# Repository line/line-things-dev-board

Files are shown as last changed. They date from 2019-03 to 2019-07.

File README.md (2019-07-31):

# LINE Things development board
LINE Things development boardは、[Nordic Semiconductor nRF52832](https://www.nordicsemi.com/Products/Low-power-short-range-wireless/nRF52832)を搭載している[Raytac MDBT42Q](http://www.raytac.com/product/ins.php?index_id=31)モジュールを搭載したLINE Things実験用ボードです。
CPUボードとマザーボードの2つの基板から構成されています。組み合わせることで動作検証をすることや、CPUボードは単体でもブレッドボード等を使って実験を行うことが可能です。

[Adafruitがオープンソースで公開しているArduinoコア](https://github.com/adafruit/Adafruit_nRF52_Arduino)を利用可能なため、Arduino IDEで簡単にLINE Thingsの機能を実験することが可能です。

この資料では各ボードの使い方、ボード上に搭載しているデバイスに関しての詳細について紹介しています。
LINE ThingsやBluetooth LEの使い方などに関してはそれぞれのページを参照してください。

- [LINE Things - LINE Developers](https://developers.line.biz/ja/docs/line-things/)
- [LINE Things dev board使用ハンズオン](https://qiita.com/cpulabs/items/3a37a70cfa41129cb024)
- [LINE の IoT プラットフォーム LINE Things の Developer Trial を試してみる](https://engineering.linecorp.com/ja/blog/line-things-developer-trial/)
- [LINE Things 自動通信機能がリリースされました & 使い方紹介](https://engineering.linecorp.com/ja/blog/line-things-automatic-communication/)

### [重要] Groveコネクタを使う方への注意点

本体のみ使用する場合は問題ありませんが、 **Groveコネクタの基板の説明に間違い** があります。

* 基板上の**P2**と**P6**の説明が逆になっています。正しくは **P2** が I2C(5V) で、**P6** が I2C(3.3V) です。
* 基板上の**P7**と**P8**は説明が逆になっています。正しくは **P7** は Grove-I/O で、**P8** が Grove-UART です。

### [重要] 加速度センサを使う方への注意点

製造ロットにより、加速度センサを搭載していないもの、または動作しないものがります。
バージョン3以降のデフォルトファームウェアでは、加速度センサを検出できない場合、「-」を表示しています。

## 目次

[Documentation on Github Pages](https://line.github.io/line-things-dev-board/)

- README.md
  - [Quick Start](#quick-start)
  - [使用方法](#使用方法)
  - [使用上の注意](#使用上の注意)
  - [ハードウェア構成](#ハードウェア構成)
  - [拡張](#拡張)
  - [回路図・アートワーク図](#回路図アートワーク図)
- docs
  - [デフォルトファームウェアについて](docs/default-firmware.md)
  - [JavaScript から LINE Things Board を制御する](docs/js-control.md)
  - [ファームウェア書き込み方法](docs/update-firmware.md)
  - [Arduino で利用できるサンプルコード](docs/examples.md)
  - [うまく動かない場合](docs/trouble-shooting.md)

## Quick Start
予め書かれているファームウェアで、LINE Thingsの機能とボード上に搭載されたデバイスの体験をすることができます。
LINE Things上でモーターを除くすべてのデバイスの状態を取得することや、LEDの制御を行うことができます。
デバイスの電源を入れ、LINE App の LINE Things から接続することで、 Notify や デバイスへの Write を試すことができます。
初期状態のファームウェアは出力パワーを最低に設定しています。端末をデバイスに近づけて利用してください。

### 初めてLINE Thingsを使用する方
初めてLINE Thingsを使用する場合、まずはLINEアプリ内のQRコードリーダーでCPU基板の裏側、またはマザーボード基板にあるQRコードを読み取って利用規約に同意してください。



### デフォルトファームウェアの機能を使う
デフォルトファームウェアでは、ファームウェアを書き換えることなく、LIFFからLINEデバイスの挙動をより高度にコントロールする機能も用意しています。
この機能を用いると、例えば任意のタイミングでデバイスからNotifyさせたり、各種センサの値を任意に設定したり、取得することが可能です。
LIFFのJavaScript APIから、このデフォルトファームウェアの機能を簡単に使うためのライブラリも用意しています。

デフォルトファームウェアの仕様については、[デフォルトファームウェアについて](docs/default-firmware.md)を参照してください。
JavaScriptライブラリについては、[JavaScript から LINE Things Board を制御する](docs/js-control.md)を参照してください。
デフォルトファームウェアを利用したLIFFは [`liff-app/linethings-dev-default/`](liff-app/linethings-dev-default/) と [`liff-app/linethings-dev-js-control/`](liff-app/linethings-dev-js-control/) に格納されています。

このファームウェアは Advertising packet の Service UUID を LIFF 上から書き換える機能を持っています。
この機能は LINE Developers から Service UUID を取得して、LINE Things developers trial の独自デバイスを構築する際に、
ファームウェアと LIFF を変更することなく独自のデバイスとして使用することを目的とした機能です。

#### LIFFからService UUIDの変更と初期化
LINE Things Developer Trialでは、プロダクト登録とそれに対応したGATT Service UUIDの設定が必要です。
デフォルトファームウェアと LIFF ([`liff-app/linethings-dev-default/`](liff-app/linethings-dev-default/), [`liff-app/linethings-dev-js-control/`](liff-app/linethings-dev-js-control/)) では、LIFF上からService UUIDを書き換えることが可能です。
この機能を用いると、Service UUIDの書換の際にデバイスのファームウェアの書き換えが不要となります。

##### LIFFからService UUIDを書き換える
LINE AppからデフォルトのLIFFを開き、Write advertising packetタブを表示します。
設定したいService UUIDをテキストボックスに入れて書き換えボタンを押すと、
Dev boardのディスプレイに「BLE advertising uuid changed from LIFF....」 と表示されていれば成功です。

ディスプレイにこのメッセージが出ていることを確認して、 **LINE AppのLINE Thingsを閉じて、dev boardのリセットボタンを押して** ください。

##### Service UUIDを初期状態に戻す
電源が入っている状態で、マザーボード上のSW1タクトスイッチを押しながら、CPUボード上のリセットボタンを押してください。
起動時に `Set advertising packet UUID to default.` とディスプレイに表示されたら成功です。

### ファームウェアをカスタマイズする
[Adafruitがオープンソースで公開しているArduinoコア](https://github.com/adafruit/Adafruit_nRF52_Arduino)を利用して、Arduino IDEから簡単に開発することが可能です。

[LINE Things Starter](https://github.com/line/line-things-starter) も、LINE Things dev board に対応しています。
Starter のリポジトリから、LINE Things dev board 用のファームウェアを書き込んでください。

デフォルトファームウェアに戻したい場合には、[`arduino/linethings-dev-default/`](arduino/linethings-dev-default) を使用してください。

ハードウェアの仕様については、[ハードウェア構成](#ハードウェア構成)を参考にしてください。
ファームウェアの書き込み方法に関しては、[ファームウェア書き込み方法](docs/update-firmware.md)を参考にしてください。
[サンプルコード](docs/examples.md)にそれぞれのデバイスを制御する方法を載せています。

---

## 使用方法
### マザーボードにCPU基板を挿して使用する
ここではCPUボードをマザーボードに挿して使用する方法を説明します。
はじめに、CPUボードをマザーボードに差し込む場合は **方向を間違えないように必ず確認** してください。Bluetoothアンテナが基板の**外側**を向くようにとおぼえておくと良いでしょう。

#### 1. 電源を選択します
マザーボードは外部電源及びUSB駆動または電池駆動をさせることが可能です。これらの設定を行う前にかならず *SW3* の電源スイッチをOFFにしてください。
USB接続の場合はUSBケーブルを抜いてください。
電源の設定は *P4* ピンで行うことができます。上側に設定することで外部電源及びUSB駆動、下側を設定すると電池駆動になります。

motherboard_power

 * 外部電源及びUSB駆動
   * *P4* を写真のように正面から見て上側に設定してください。
 * 電池駆動
   * *P4* を写真のように正面から見て下側に設定してください。

※単4電池駆動の場合5V系は使用できません。外部電源駆動にして使用してください。 \
※USB電源駆動ではモーターを使用しないでください。外部電源駆動にして使用してください。

#### 2. 電源をONにします。

* 外部電源及びUSB駆動
  * *CN3* に電源を、またはUSBケーブルを接続してください。電源スイッチにかかわらずデバイスがONになります。
* 電池駆動
  * 電池を搭載して、*SW3* の電源スイッチをON(上側)にしてください。

電源LED(*DS1*)が光っていることを確認してください。以上で使用できる準備が整いました。

### CPU基板単体で使用する
電源さえ給電すれば単体動作可能となります。Resetピンは内部でプルアップしているので使用しない場合は非接続で構いません。

## 使用上の注意
### CPUボード
motherboard_direction

 * マザーボードに差し込む場合は必ず方向を間違えないように確認してください。
 * CPUボードを単体で使用する場合、安定したBLEの通信を行うため、アンテナが配置されている側をなるべくGNDや他の電極パターンに近づけないでください。ブレッドボード上に配置する場合は、アンテナをブレッドボードの端になるようにしてください。
 * BLE通信を行う場合、アンテナが露出していることが望ましいです。ケースに入れる場合は金属ケースなどを使用せず、プラスチックケースを使用してください。

### マザーボード
 * 基板上のP7とP8は説明が逆になっています。正しくはP7はGrove-I/Oで、P8がGrove-UARTです。
 * 基板上の説明ではP6にGrove-I2C 5Vと記載されていますが、正しくはP6がI2C(3.3V)、P2がI2C(5V)となります。
 * 電源供給として電池を使用する場合は、電池の極性を間違えないようにしてください。間違えた場合デバイスが破損してしまうことがあります。
 * 3.3Vを外部に供給する場合は、CPU基板を含め全体で600mAを超えない範囲で使用してください。超えてしまうと電源ICが破損してしまうことがあります。
 * 外部電源を使用する場合は必ず電圧と極性を確認してください。
 * 一部パターンのみ用意されていて、はんだ付けされていない部品があります。必要に応じて適宜追加してください。

---

## ハードウェア構成
### CPUボード
cpuboard

[Raytac MDBT42Q](http://www.raytac.com/product/ins.php?index_id=31)モジュールを搭載しています。
AdafruitのArduinoコアを利用可能でArduino IDEを使用して開発することができ、J-LINKなどから利用できるJTAG(SWD)ポートを用意しているので、
Arduinoではなくご自身でフルスクラッチ開発も可能となっています。マザーボードに挿して使用することも、CPUボード単体で使用することも可能です。

#### ピンアサイン
cpuboard_pinassign

#### 技術仕様
CPUボード単体での仕様です。マザーボードに接続して使用する場合、そちらの仕様が適用されます。

| 項目 | 値 |
----|----
| 動作可能電圧 | 1.7~3.6V |
| 最大RFパワー | 4dBm |
| Flashサイズ | 512KB |
| RAMサイズ | 64KB |

### マザーボード
motherboard

マザーボード上にはLED、タクトスイッチ、温度センサやOLEDなどを搭載しています。
使用する際はCPUボードを挿して使用します。**CPUボードを挿す際は向きに注意** してください。向きを間違うと
デバイスが壊れてしまうこともあるのでご注意ください。

#### 技術仕様
| 項目 | 値 |
----|----
| 電源ソース | 電池/USB/外部供給 |
| 動作可能電圧(電池) | 3V(単4電池1.5Vを２本直列) |
| 動作可能電圧(USB) | 5V |
| 動作可能電圧(外部供給) | 5V |
| 最大連続消費電流(電池駆動/モーター未使用) | 0.6A |
| 最大連続消費電流(モーター使用時) | 2.6A |

## マザーボード搭載デバイス
5V系統と記載があるものは電池駆動では使用できません。外部電源を使用するかUSB接続で使用する必要があります。また、GroveコネクタやGPIOにて3.3V駆動デバイスに5V系統を接続したり、
逆に5V駆動デバイスに3.3V系統を接続すると、マイコンや接続デバイスの破損につながるため、接続する電源系統はご注意ください。

特に記載がないものは3.3V系統です。5V系統のものに関しては明示的に記載しております。

### LED
LEDはアノード側がマイコンに接続されています。よってマイコンでHighを出力するとLEDが点灯します。使用する際はポートを出力設定にしてください。

| 基板上番号 | マイコンピン番号 |
----|----
| DS2 | 7 |
| DS3 | 11 |
| DS4 | 19 |
| DS5 | 17 |

### タクトスイッチ
タクトスイッチは回路上でプルアップしていないので、必ずマイコン側でプルアップ付き入力(INPUT_PULLUP)で使用してください。

| 基板上番号 | マイコンピン番号 |
----|----
| SW1 | 29|
| SW2 | 28 |

### ブザー
圧電ブザーが搭載されています。このブザーで音を鳴らすにはマイコンから交流信号を出力する必要があります(マイコンの出力をHighにしただけでは出力されません)。
通常のArduinoであればtone()関数で任意の音を出すことが可能ですが、nRF52832のArduino環境ではこれを使うことができません。よってタイマー割り込みなどでON/OFFを繰り返して音を鳴らす必要があります。
ここで紹介しているサンプルではFreeRTOSのタイマーを使って1KHzの割り込みを作り、そこでピンの状態を反転することで500Hzのブザー音を生成しています。
より高い周波数で鳴らしたい場合は、nRF52832のハードウェアタイマーを設定する必要があります。

| 基板上番号 | マイコンピン番号 |
----|----
| BZ1 | 27 |

### OLED
128x64ピクセルの有機EL(SSD1306)を搭載しています。I2Cで接続されており、
Adafruit SSD1306などのライブラリを使用すると簡単に使うことができます。I2Cのアドレスは0x3Dとなります。

| ピン名称 | マイコンピン番号 |
----|----
| SCL | 26 |
| SDA | 25 |

### 温度センサ
温度センサ(AT30TS74)を搭載しています。I2Cで接続されており、
簡単な制御で使うことができます。I2Cのアドレスは0x48となります。

| デバイスピン | マイコンピン番号 |
----|----
| SCL | 26 |
| SDA | 25 |

### 加速度センサ
加速度センサ(MMA8452Q)を搭載しています。I2Cで接続されており、
SparkFun MMA8452Q Accelerometerライブラリを使うと簡単な制御で使うことができます。I2Cのアドレスは0x1Cとなります。

| デバイスピン | マイコンピン番号 |
----|----
| SCL | 26 |
| SDA | 25 |

#### 注意事項
* 製造ロットにより、加速度センサを搭載していないもの、または動作しないものがります。
バージョン3以降のデフォルトファームウェアでは、加速度センサを検出できない場合、「-」を表示しています。

### モーター
モータードライバ(DRV8830)を2つ搭載することが可能です。I2Cで接続されており、
簡単な制御で使うことができます。モーターは *CN1* と *CN2* に接続することが可能です。I2Cのアドレスは0x60(CN1)、0x62(CN2)となります。

| デバイスピン | マイコンピン番号 |
----|----
| SCL | 26 |
| SDA | 25 |

#### 注意事項
* 初期状態でモータードライバは搭載されていません。使用するにはいくつかの部品を取り外し、必要な部品をご自身ではんだ付けする必要があります。
詳しくは[モータードライバ](#モータードライバ)を御覧ください。
* 5V系統です。電池駆動ではご使用になれません。使用する場合は外部電源またはUSB給電をする必要があります。

### Grove端子(I2C)
基板上では端子 *P6* となります。(基板上の説明ではP6にGrove-I2C 5Vと記載されていますが、正しくはP6がI2C-3.3V、P2がI2C-5Vとなります)

| コネクタピン番号 | ピン名称 | マイコンピン番号 |
----|----|----
| 1 | SCL | 26 |
| 2 | SDA | 25 |
| 3 | 3.3V  | - |
| 4 | GND | - |

#### 注意事項
* 初期状態でこのコネクタは搭載されていません。使用するにはGroveコネクタをご自身ではんだ付けする必要があります。
* 基板上の説明ではP6にGrove-I2C 5Vと記載されていますが、正しくはP6がI2C-3.3V、P2がI2C-5Vとなります。

### Grove端子(I2C / 5V系統)
基板上では端子 *P2* となります。

| コネクタピン番号 | ピン名称 | マイコンピン番号 |
----|----|----
| 1 | SCL | 26 |
| 2 | SDA | 25 |
| 3 | 5V  | - |
| 4 | GND | - |

#### 注意事項
* 初期状態でこのコネクタは搭載されていません。使用するにはGroveコネクタをご自身ではんだ付けする必要があります。
* 基板上の説明ではP6にGrove-I2C 5Vと記載されていますが、正しくはP6がI2C-3.3V、P2がI2C-5Vとなります。
* 5V系統です。電池駆動ではご使用になれません。使用する場合は外部電源またはUSB給電をする必要があります。
* 接続する機器は5Vで動作するものを接続してください。3.3Vのデバイスを接続するとデバイスが破損する可能性があるのでご注意ください。

### Grove端子(UART)
基板上に *P8 / Grove-I/O* と印刷されているコネクタです。（P7はGrove-I/Oで、P8がGrove-UARTです）

| コネクタピン番号 | ピン名称 | マイコンピン番号 |
----|----|----
| 1 | RxD | 6 |
| 2 | TxD | 8 |
| 3 | 3.3V  | - |
| 4 | GND | - |

#### 注意事項
* 初期状態でこのコネクタは搭載されていません。使用するにはGroveコネクタをご自身ではんだ付けする必要があります。

### Grove端子(汎用デジタルI/O)
基板上に *P7 / Grove-UART* と印刷されているコネクタです。（P7はGrove-I/Oで、P8がGrove-UARTです）

| コネクタピン番号 | ピン名称 | マイコンピン番号 |
----|----|----
| 1 | D0 | 2 |
| 2 | D1 | 3 |
| 3 | 3.3V  | - |
| 4 | GND | - |

#### 注意事項
* 初期状態でこのコネクタは搭載されていません。使用するにはGroveコネクタをご自身ではんだ付けする必要があります。

### GPIO
基板上では端子 *P1* となります。

6ピンはリセットピンです。Lowにすることでマイコンをリセットすることが可能です。CPU基板側でプルアップされているため、未使用の場合は非接続で構いません。

| コネクタピン番号 | ピン名称 | マイコンピン番号 |
----|----|----
| 1 | I/O | 2 |
| 2 | 5V | - |
| 3 | I/O | 3 |
| 4 | 3.3V | - |
| 5 | I/O | 4 |
| 6 | RESET | - |
| 7 | I/O | 5 |
| 8 | I/O | 26(SCL) |
| 9 | I/O | 12(SCK) |
| 10 | I/O | 25(SDA) |
| 11 | I/O | 13(MOSI) |
| 12 | I/O | 16 |
| 13 | I/O | 14(MISO) |
| 14 | I/O | 15 |
| 15 | I/O | 8(RxD) |
| 16 | O | 11(LED-DS3) |
| 17 | I/O | 6(TxD) |
| 18 | O | 7(LED-DS2) |
| 19 | GND |  |
| 20 | GND |  |

#### 注意事項
* 8, 10ピンはI2C端子に接続されています。このピンはボード上のI2Cデバイスでも使用しているため、汎用I/OではなくI2Cピンとして使用することを強くおすすめします。
* 15, 17ピンはUART端子に接続されています。このピンはファームウェアの書き込み等でも使用しているため、汎用I/OではなくUARTピンとして使用することを強くおすすめします。
* 16, 18ピンはボード上でLED端子に接続されています。そのため、基本的にOutput端子として使用してください。

## 拡張
### モータードライバ
マザーボードはモータードライバが実装されていないため、そのままではモーターを使用することができません。
モーターを使用したい場合は *R18* (0オーム)を取り外して、以下の部品を新規に追加実装してください。

DRV8830DGQRは裏のGNDパッドを基板の裏側からハンダを流してはんだ付けしてください。

| 追加部品基板シルク | 部品 | パラメータ |
----|----|----
| U1 | IC | DRV8830DGQR |
| U2 | IC | DRV8830DGQR |
| L1 | コイル | 100uF / 2A |
| C1 | コンデンサ | 1000pF |
| C2 | コンデンサ | 1000pF |
| C13 | コンデンサ | 100uF / 16V |
| C14 | コンデンサ | 470uF / 16V |
| R10 | 抵抗 | 0.2Ω / 2W |
| R11 | 抵抗 | 0.2Ω / 2W |
| CN1 | コネクタ | JST-XH-02P |
| CN2 | コネクタ | JST-XH-02P |

### 電源 / Groveコネクタ
電源コネクタはJST-XH-02Pコネクタを使用しています。Groveコネクタは4Pの標準のものを使用しています。

### 電池ボックス
電池ボックスは共立電子産業さん、または秋月電子通商さんにて購入可能な単4電池ボックスを2つ使用しています。

- http://eleshop.jp/shop/g/g6CM128/
- http://akizukidenshi.com/catalog/g/gP-02670/

## 回路図・アートワーク図
- CPU ボード
    - [回路図](https://github.com/line/line-things-dev-board/blob/master/schematics/cpu_board/Outputs/schematic.pdf)
    - [アートワーク図 - 表](https://github.com/line/line-things-dev-board/blob/master/schematics/cpu_board/Outputs/pcb_top.pdf)
    - [アートワーク図 - 裏](https://github.com/line/line-things-dev-board/blob/master/schematics/cpu_board/Outputs/pcb_bottom.pdf)
- マザーボード
    - [回路図](https://github.com/line/line-things-dev-board/blob/master/schematics/main_board/Outputs/schematic.pdf)
    - [アートワーク図 - 表](https://github.com/line/line-things-dev-board/blob/master/schematics/main_board/Outputs/pcb_top.pdf)
    - [アートワーク図 - 裏](https://github.com/line/line-things-dev-board/blob/master/schematics/main_board/Outputs/pcb_bottom.pdf)

### 自分で基板を製造したい
- [`/cpu_board/Outputs/`](/cpu_board/Outputs/)
- [`/main_board/Outputs/`](/main_board/Outputs/)

基板製造に必要なガーバーデータがここに格納されています。実装に必要な部品リストは bom_{cpu/main}_board.xls を使用してください。
なお、回路図及び基板データは Altium 社の Circuit Studio でデザインしています。設計データを変更する場合、Circuit Studio から開いてください。
https://www.altium.com/circuitstudio/

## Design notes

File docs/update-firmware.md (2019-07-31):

# ファームウェア書き込み方法
ここではArduino IDEを使用する方法を説明します。

## Arduino環境とドライバの準備
Arduino IDE をインストールた後、必ずボードを **接続しないで** 以下の手順を進めてください。

1. Arduino IDE を開きます
2. **Preferences** を開いてください
3. 'Additional Board Manager URL' に `https://www.adafruit.com/package_adafruit_index.json` を追加します
4. Tools -> Board menu　から **Boards Manager** を開いてください
5. "nRF52" と検索して、**Adafruit nRF52 by Adafruit** をインストールしてください (Version 0.11.0 以上をインストールしてください)
(*Note: Linux をお使いの方は追加でソフトウェアの設定が必要です、[こちらをご覧ください](https://learn.adafruit.com/bluefruit-nrf52-feather-learning-guide/arduino-bsp-setup)*)
6. [CP2102N driver](https://www.silabs.com/products/development-tools/software/usb-to-uart-bridge-vcp-drivers) をインストールします

## デフォルトファームウェア用のライブラリをインストール
デフォルトファームウェア ([`arduino/linethings-dev-default/`](/arduino/linethings-dev-default)) を利用する場合には、以下のライブラリが必要です。
Arduino のライブラリマネージャーからインストールしてください。

- [SparkFun MMA8452Q Accelerometer](https://github.com/sparkfun/SparkFun_MMA8452Q_Arduino_Library)
- [Adafruit GFX Library](https://github.com/adafruit/Adafruit-GFX-Library)
- [Adafruit SSD1306](https://github.com/adafruit/Adafruit_SSD1306)

また、温度センサーを動作させるために、`things_temp_lib` ライブラリを利用しています。
`things_temp_lib` は `library/things_temp_lib` をzipファイルに圧縮して、ライブラリをインクルードからインストールしてください。

## ハードウェアセットアップ
### マザーボードにCPU基板を刺して使用する
1. CPUボードがマザーボードに刺さっていることを確認してください
2. USB端子(J1)にMicro-USBケーブルを使ってPCへ接続してください
3. Tools -> Board のリストから **Adafruit Bluefruit Feather nRF52832** を選択してください
4. Under Tools -> Port で正しいシリアルポートを選択してください *ie. COM1, /dev/cu.SLAB_USBtoUART*
5. テストとして、一度空のスケッチをアップロードしてみましょう。エラーがでなければ問題ありません。

### CPU基板単体で使用する - マザーボードの書き込み機を利用
1. 下記図のようにCPUボードの *RxD*/*TxD*/*Reset*/*VCC*/*GND* ピンをジャンパ線などを使用してマザーボードに接続してください。ピンアサインはCPUボードのピンアサインを参照してください。
2. USB端子(*J1*)にMicro-USBケーブルを使ってPCへ接続してください
3. Tools -> Board のリストから **Adafruit Bluefruit Feather nRF52832** を選択してください
4. Under Tools -> Port で正しいシリアルポートを選択してください *ie. COM1, /dev/cu.SLAB_USBtoUART*
5. テストとして、一度空のスケッチをアップロードしてみましょう。エラーがでなければ問題ありません。

motherboard_external

### CPU基板単体で使用する - 市販されている書き込み機を使用(非推奨)
DTR信号を出力できるアダプタであれば市販されているUSB-TTL変換アダプタ (CP2102搭載基板等) を使って書き込むことができます。この他に0.1uFのセラミックコンデンサが必要です。

1. 下記図のようにCPU基板の *RxD*/*TxD*/*Reset*/*VCC*/*GND* ピンをジャンパ線などを使用して書き込み機に接続してください(**ResetピンとDTRピンの間には0.1uFのセラミックコンデンサを挟んでください**)
2. USB端子(*J1*)にMicro-USBケーブルを使ってPCへ接続してください
3. Tools -> Board のリストから **Adafruit Bluefruit nRF52 Feather** を選択してください
4. Under Tools -> Port で正しいシリアルポートを選択してください *ie. COM1, /dev/cu.SLAB_USBtoUART*
5. テストとして、一度空のスケッチをアップロードしてみましょう。エラーがでなければ問題ありません。

| 書き込み器側 | CPU基板側 | 注意点 |
----|----|----
| VDD(3.3V) | P28 | |
| GND | P1 | |
| DTR | P27 | 間に0.1uFのコンデンサを挟んでください |
| RxD | P6 | |
| TxD | P8 | |

cpuboard_prog_external

## 詳しい人向け
### J-LINKでの書き込み
J-LINKを使うとより高レベルのデバッグや、Arduinoを使用しない開発が可能となります。写真で示すJ-LINKコネクタの通りにデバッガを接続してください。
なお、J-LINKを使用して書き込みを行うと、もとのブートローダが破壊され、Arduino環境でのIDEが使用できなくなります。
さらに、工事設計認証(技適)を無効化してしまう可能性があります。よくわかる方のみ、ご自身の責任で行ってください。再度Arduino環境で使用できるように戻したい場合、
[Bootloaderを書き込む](#bootloaderを書き込む) を参考にして行ってください。

#### 配線図
cpuboard_jlink

| コネクタピン番号 | ピン名称 |
----|----|
| 1 | SWDIO |
| 2 | GND |
| 3 | SWDCLK |
| 4 | VCC |

### AdafruitのBootloaderを書き込む
一度、J-LINKを利用して書き込みを行い既存のブートローダーを破壊してしまった場合、初期状態のArduino開発環境を利用できるようにするには、Adafruitのブートローダーを再度書き込む必要があります。
作業にあたってはJ-LINKが必要となります。

[Arduino Core for Adafruit Bluefruit nRF52 Boards - Burning new Bootloader](https://github.com/adafruit/Adafruit_nRF52_Arduino/#burning-new-bootloader)を参考にして書き込みを行ってください。

※ 正常にArduino IDEから使用できている場合はこの作業を行わないでください。Bootloaderのバージョンを上げる場合は[Bootloaderの更新方法](#bootloaderの更新方法)を参考にしてください。

### Bootloaderの更新方法
Adafruit のページにアップデート方法が記載されています。この通りに行ってください。

https://learn.adafruit.com/bluefruit-nrf52-feather-learning-guide/updating-the-bootloader

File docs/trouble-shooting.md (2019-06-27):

# うまく動かない場合
## Bluetooth LEのデバイスが見つからない・通信がうまくできない
使用している端末のキャッシュが悪さをしている可能性があります。端末の設定からBluetoothをON/OFFしたり、一番確実なのは端末を再起動してみることです。

## Arduino IDEから書き込みや通信ができない・エラーが出る
Arduino IDEの `ツール -> ボード` で `Adafruit Bluefruit nRF52832 Feather` が選択されているか確認してください。
この項目がない場合はファームウェア書き込み方法 : Arduino環境とドライバの準備を参考にして環境構築を行ってください。

また、`ツール -> シリアルポート` で正しいポートが選択されているか確認してください。

これでもうまくいかない場合、ブートローダーや SoftDevice のバージョンの整合性が取れていなかったり、何らかの原因でブートローダが壊れてしまった可能性があります。
再度、ブートローダーを Arduino IDE から書き込むことで、書き込めるようになる可能性があります。
ブートローダーの書き込み方法は、[Arduino Core for Adafruit Bluefruit nRF52 Boards - Bootloader Support](https://github.com/adafruit/Adafruit_nRF52_Arduino/#bootloader-support) を参考にして行ってください。

## 電源LED(*DS1*)が光らない
電源設定ジャンパー(*J4*)が正しく設定されているか確認してください。USB電源または外部電源を使用している場合は上に、電池駆動の場合は下向きにジャンパーが入っていることを確認してください。電池駆動の場合、電池が正しい向きで挿入されているか確認してください。

## モーターが動かない
初期状態ではモーター駆動に必要な部品が搭載されていません。それらの部品をご自身で取り付ける必要があります。詳しくは [モータードライバ](#モータードライバ) を御覧ください。
部品を取り付けたのにもかかわらず動かない場合は、まずははんだ付けが正しく行われているか確認してください。

また、電池駆動ではモーターを動かすことはできません。USBまたは外部電源でのみ使用できます。

## 正しく動いていたものがデバッグ中に突然動かなくなった
I2Cデバイス(マザーボード上であればOLEDディスプレイ、温度センサ、加速度センサ)を使用している場合、それらの通信が何らかの原因でできなくなり、デッドロックになっている可能性があります。リセットではなく、一度電源を切ってから再度入れてみてください。

## モーターの制御が安定しない
DRV8830DGQRの裏側のGNDパッドがはんだ付けされていない可能性があります。なくても動きますが不安定になることがあります。基板の裏側からハンダを流し入れてください。

## Arduinoでサンプルファイルのコンパイルが通らない
Arduino の `Tools -> Board menu` から **Boards Manager** を開いて、"nRF52" と検索して、**Adafruit nRF52 by Adafruit** を見つけます。
インストールされているバージョンが **0.11.0** より古い場合は、アップデートしてください。

## デフォルトファームウェアのUUIDを変更して書き込んだが古いUUIDのまま変わらない
デフォルトサンプルファームウェアではUUIDを内蔵Flashに記憶しています。ファームウェア上で変更したUUIDを反映させるには、ファームウェアを書き込んだあとにUUIDの初期化を行い、
Flash上に記載されたUUIDを上書きをする必要があります。

[Service UUIDを初期状態に戻す](#service-uuidを初期状態に戻す)を参照して行ってください。

次に、スマートフォン側で、OS の Bluetooth デバイス連携画面からデバイス登録を解除し、その後 LINE App上の LINE Things のデバイス連携画面からも解除を行います。
通常、これで新たUUIDのデバイスと接続できるようになりますが、それでもだめな場合は LINE App を Kill して、OS の Bluetooth デバイス管理画面から Bluetooth を OFF/ON してみます。
これでも見つからない場合は、OS を再起動してください。

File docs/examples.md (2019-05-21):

# Arduino で利用できるサンプルコード

Arduino で、LINE Things development board 搭載デバイスを動作させるためのサンプルコードです。
ファームウェアの書き込み方法は、[ファームウェア書き込み方法](update-firmware.md) を参考にしてください。

## サンプルコード - LED
```cpp
/**
 * サンプルコード - LED
 * 0.5秒ごとにDS2~5が点灯してすべて点灯したら0.5秒に消灯を繰り返す
 */

const int LED_DS2 = 7;
const int LED_DS3 = 11;
const int LED_DS4 = 19;
const int LED_DS5 = 17;

void setup() {
  // LEDのピンを出力に設定
  pinMode(LED_DS2, OUTPUT);
  pinMode(LED_DS3, OUTPUT);
  pinMode(LED_DS4, OUTPUT);
  pinMode(LED_DS5, OUTPUT);
}

void loop() {
  // 500mSごとにLED_DS2~5を点灯
  digitalWrite(LED_DS2, HIGH);  // LED_DS2を点灯
  delay(500);                   // 500mS待つ
  digitalWrite(LED_DS3, HIGH);
  delay(500);
  digitalWrite(LED_DS4, HIGH);
  delay(500);
  digitalWrite(LED_DS5, HIGH);
  delay(500);
  // LED_DS2~5を消灯
  digitalWrite(LED_DS2, LOW);  // LED_DS2を消灯
  digitalWrite(LED_DS3, LOW);
  digitalWrite(LED_DS4, LOW);
  digitalWrite(LED_DS5, LOW);
  delay(500);
}
```

## サンプルコード - タクトスイッチ
```cpp
/**
 * サンプルコード - タクトスイッチ
 * SW1が押されているときだけLED_DS2が点灯
 */

const int LED_DS2 = 7;
const int SW1 = 29;

void setup() {
  // スイッチをプルアップ付き入力に設定
  pinMode(SW1, INPUT_PULLUP);
  // LEDのピンを出力に設定
  pinMode(LED_DS2, OUTPUT);
}

void loop() {
  // SW1が押されているときだけLED_DS2が点灯
  digitalWrite(LED_DS2, !digitalRead(SW1));
}
```

## サンプルコード - ブザー
```cpp
/**
 * サンプルコード - ブザー
 * 0.5秒ごとにブザーがON/OFFします
 */

const int BUZZER_PIN = 27;
SoftwareTimer buzzer;

// ブザーを鳴らすために1KHzの周期でイベントを生成
void buzzerEvent(TimerHandle_t xTimerID) {
  digitalWrite(BUZZER_PIN, !digitalRead(BUZZER_PIN));
}

void buzzerStart() {
  pinMode(BUZZER_PIN, OUTPUT);
  buzzer.begin(1, buzzerEvent);
	buzzer.start();
}

void buzzerStop() {
  buzzer.stop();
  digitalWrite(BUZZER_PIN, 0);
}

void setup() {
}

void loop() {
  buzzerStart();
  delay(500);
  buzzerStop();
  delay(500);
}
```

## サンプルコード - OLED
```cpp
/**
 * サンプルコード - OLED
 * `Adafruit SSD1306` と `Adafruit GFX Library` ライブラリをインストールしてください
 */

#include <Adafruit_SSD1306.h>
#include <Adafruit_GFX.h>
#include <Wire.h>

// ディスプレイのインスタンスを生成
Adafruit_SSD1306 display(128, 64, &Wire, -1);

void setup() {
  // ディスプレイの初期化
  display.begin(SSD1306_SWITCHCAPVCC, 0x3C);    // ディスプレイの表示に必要な電圧を生成, アドレスは0x3C
  display.clearDisplay();                       // ディスプレイのバッファを初期化
  display.display();                            // ディスプレイのバッファを表示
}

void loop() {
  // テキストを描画
  display.setTextSize(1);                       // テキストサイズ1
  display.setTextColor(WHITE);                  // Color White
  display.setCursor(0,10);                      // X=0, Y=10
  display.println("LINE Things");
  display.println("Starter Board");
  display.display();                            // ディスプレイのバッファを表示
  delay(1000);
  // 線を描画
  display.drawLine(0, 32, 128, 32, WHITE);      
  display.display();
  delay(1000);
  // 四角を描画
  display.fillRect(20, 40, 20, 20, WHITE);
  display.display();
  delay(1000);
  // 丸を描画
  display.fillCircle(100, 50, 10, WHITE);
  display.display();
  delay(1000);
  // 表示をクリア
  display.clearDisplay();                       // ディスプレイのバッファを初期化
  display.display();                            // ディスプレイのバッファを表示
  delay(100);
}
```

## サンプルコード - 温度センサ
```cpp
/**
 * サンプルコード - 温度センサ
 * 温度を読み込んでOLEDに表示するサンプルです。温度の表示にOLEDを使っています。
 * `library/things_temp_lib.zip` をライブラリをインクルードからインストールしてください
 * `Adafruit SSD1306` と `Adafruit GFX Library` ライブラリを管理からインストールしてください
 */

#include <Wire.h>
#include <Adafruit_SSD1306.h>
#include <Adafruit_GFX.h>
#include <linethings_temp.h>

//ディスプレイのインスタンスを生成
Adafruit_SSD1306 display(128, 64, &Wire, -1);

ThingsTemp temp = ThingsTemp();

void setup() {
  // ディスプレイの初期化
  display.begin(SSD1306_SWITCHCAPVCC, 0x3C);    // ディスプレイの表示に必要な電圧を生成, アドレスは0x3C
  display.clearDisplay();                       // ディスプレイのバッファを初期化
  display.display();                            // ディスプレイのバッファを表示

  // 温度センサの初期化
  temp.init();
}

void loop() {
  // 温度を取得
  float data = temp.read();
  // 温度を表示
  display.clearDisplay();                       // ディスプレイのバッファを初期化
  display.setTextSize(1);                       // テキストサイズ1
  display.setTextColor(WHITE);                  // Color White
  display.setCursor(0,10);                      // X=0, Y=10
  display.println("LINE Things");
  display.println("Starter Board");
  display.print("Temperature:");
  display.print(data);
  display.println("C");
  display.display();                            // ディスプレイのバッファを表示
  delay(1000);
}
```

## サンプルコード - 加速度センサ
```cpp
/**
 * サンプルコード - 加速度センサ
 * 加速度センサの値を読み込んでOLEDに表示するサンプルです。表示にOLEDを使っています。
 * `SparkFun MMA8452Q Accelerometer` ライブラリを管理からインストールしてください
 * `Adafruit SSD1306` と `Adafruit GFX Library` ライブラリを管理からインストールしてください
 */

#include <Wire.h>
#include <Adafruit_SSD1306.h>
#include <Adafruit_GFX.h>
#include <SparkFun_MMA8452Q.h>

// ディスプレイのインスタンスを生成
Adafruit_SSD1306 display(128, 64, &Wire, -1);
// 加速度センサのインスタンスを生成 (アドレス: 0x1c)
MMA8452Q accel(0x1c);

void setup() {
  // ディスプレイの初期化
  display.begin(SSD1306_SWITCHCAPVCC, 0x3C);    // ディスプレイの表示に必要な電圧を生成, アドレスは0x3C
  display.clearDisplay();                       // ディスプレイのバッファを初期化
  display.display();                            // ディスプレイのバッファを表示

  // 加速度センサの初期化
  accel.init(SCALE_2G);
}

void loop() {
  // 加速度センサから値を取得
  if (accel.available()) {
    accel.read();
  }

  // 加速度センサの値を表示
  display.clearDisplay();                       // ディスプレイのバッファを初期化
  display.setTextSize(1);                       // テキストサイズ1
  display.setTextColor(WHITE);                  // Color White
  display.setCursor(0,10);                      // X=0, Y=10
  display.println("LINE Things");
  display.println("Starter Board");
  display.print("X:");
  display.println(accel.cx);
  display.print("Y:");
  display.println(accel.cy);
  display.print("Z:");
  display.println(accel.cz);
  display.display();                            // ディスプレイのバッファを表示
  delay(300);
}
```

## サンプルコード - モーター
```cpp
/**
 * サンプルコード - モーター
 * 2つのモーターを制御するサンプルです
 * library/things_motor_lib.zipをライブラリをインクルードからインストールしてください
 */

#include <linethings_motor.h>

ThingsMotor motor_cn1 = ThingsMotor(MOTOR_ADDR_CN1);
ThingsMotor motor_cn2 = ThingsMotor(MOTOR_ADDR_CN2);

int i = 0;

void setup() {
  motor_cn1.init();
  motor_cn2.init();
}

void loop() {
  motor_cn1.control(MOTOR_BACK, i);
  motor_cn2.control(MOTOR_FORWARD, i);
  delay(100);
  i++;
  if (i >= 100) {
    i = 0;
  }
}
```

## マザーボード上以外のデバイスを使ったサンプルスケッチ

### フルカラー LED - NeoPixel
neopixel

一般的にNeopixelとよばれる、WS2812B搭載のフルカラーLEDを光らせるデモです。LEDの光の輝度を時間とともに0~100%でコントロールしています。マザーボード上の *SW1* を押すことでLEDの色を変えることができます。
GPIOの1ピン(マイコン *IO2*)にNeopixelのIN端子を、GPIOの3番ピン(3.3V)を *VCC*、20番ピン(GND)を *GND* に接続します。本来WS2812Bは5Vで使用するものですが、3.3V電源でも一応動くことを確認しています。

ファームウェアは `arduino/linethings-dev-neopixel/linethings-dev-neopixel.ino` を使用してください。
使用する基板に搭載されたLED数に従って `NEOPIXEL_PIXELS` の値を変更してください。初期値は16個のLEDを制御します。

Adafruit_NeoPixelライブラリを使用しています。ライブラリを管理から `adafruit neopixel` と検索して見つかる `Adafruit Neopixel by Adafruit` をインストールしてください。

### RC car
マザーボード上に搭載されたモータードライバを使ったラジコンです。LINE Thingsを使ってコントロールすることが可能です。
ファームウェアは `arduino/linethings-dev-car/linethings-dev-car.ino` を使用してください。LIFFは `liff-app/linethings-dev-car/` においてあるものを使用します。

### 注意事項
* マザーボード基板上の電池のみでは動作しません。外部電源コネクタを使用して給電します。
* USB電源はパソコンなどから給電すると電圧が不安定になり動作しない場合があります。また流れる電流に注意が必要なのでおすすめしません。

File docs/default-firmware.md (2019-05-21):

# デフォルトファームウェアについて

## GATT サービスの仕様
デフォルトファームウェアに実装されているGATTサービス・キャラクタリスティックの仕様について説明します。
ここからの説明は[JavaScriptライブラリ](js-control.md)を使用する際には不要ですが、拡張したり、LIFF以外からデバイスを制御する場合に必要な情報です。

### Characteristic の説明
PSDIを除く全てのCharacteristicは、以下のサービスに実装されています。

- `DEVBOARD_SERVICE_UUID`
  - `f2b742dc-35e3-4e55-9def-0ce4a209c552`

このサービスに実装されている Characteristic と UUID は以下の通りです。

|説明 | 名称 | UUID | 属性 | サイズ(固定長) |
----|----|----|----|----
| 1 | WRITE_BOARD_STATE_CHARACTERISTIC_UUID | 4f2596d7-b3d6-4102-85a2-947b80ab4c6f | Write | 20Byte |
| 2 | VERSION_CHARACTERISTIC_UUID | be25a3fe-92cd-41af-aeee-0a9097570815 | Read | 1Byte |
| 3 | NOTIFY_SW_CHARACTERISTIC_UUID | a11bd5c0-e7da-4015-869b-d5c0087d3cc4 | Notify | 2Byte |
| 4 | NOTIFY_TEMP_CHARACTERISTIC_UUID | fe9b11a8-5f98-40d6-ae82-bea94816277f | Notify | 2Byte |
| 5 | COMMAND_WRITE_CHARACTERISTIC_UUID | 5136e866-d081-47d3-aabc-a2c9518bacd4 | Write | 18Byte |
| 6 | COMMAND_RESPONSE_CHARACTERISTIC_UUID | 1737f2f4-c3d3-453b-a1a6-9efe69cc944f  | Read + Notify | 4Byte |

1. JavaScriptライブラリ内では、Service UUIDの書き換えのみで使用しています。
2. Dev boardのファームウェアのバージョンを取得します。デバイス側で定義されていない場合はVersion 1とします。
3. Switchのnotifyが有効化されているとき、スイッチイベントが発生するときにnotifyします。
4. 温度センサのnotifyが有効化されているとき、一定間隔で温度をnotifyします。
5. Dev boardのデバイスの設定や、notifyの設定など、コマンドを書き込むために使用します。
6. Dev boardから、コマンドに対応したデータがある場合、それを取得するために利用します。Notify にも対応しています。

### WRITE_BOARD_STATE_CHARACTERISTIC_UUID (Service UUIDの書き換え)
Service UUIDの書き換えを行うためのキャラクタリスティックです。
`Write device`はボード上のデバイスの値を書き換えることができますが、これは `/liff-app/linethings-dev-default` が使用しているものです。

フォーマット

| |Command (1Byte) | reserved (2Byte) | hash (1Byte) | payload (16Byte) | 説明 |
----|----|----|----|----|----
| Write device | 0 | {0, 0} | 0 | see code | ボード上のデバイスとGPIOを一括設定する際に使用します。Version 1から使用できます|
| Write Service UUID | 1 | {0, 0} | hash of uuid | uuid | hashはUUIDをリダクション加算した値を使用します。UUIDは"-"は省略します |

### VERSION_CHARACTERISTIC_UUID (ファームウェアのバージョン取得)
Firmwareのバージョンを取得します。Version 1ではこのキャラクタリスティックが実装されていませんでした。
そのため、LIFF側からこのキャラクタリスティックのReadがerrorとなった場合は
Version 1であるとして、Version 2以降で追加となったService UUIDの書き換え機能以外は非対応としなくてはいけません。

### NOTIFY_SW_CHARACTERISTIC_UUID (SW Notify)
スイッチが押されたタイミングでnotifyをします。
`DEFAULT_CHARACTERISTIC_IO_WRITE_UUID`にてSWのnotifyの設定が可能です。
初期状態では、source = SW1 & SW2, mode = `CHANGE`, interval = 50ms に設定されています。

フォーマット

|value[1]|value[0]|
----|----
|address(1:SW1, 2:SW2)|SW value|

### NOTIFY_TEMP_CHARACTERISTIC_UUID (Temperature Notify)
`DEFAULT_CHARACTERISTIC_IO_WRITE_UUID`にて温度のnotitfyが有効化された場合、設定されたタイミングでnotifyをします。
notifyされる16Byteの温度データは100倍されたものが送信されます。

初期状態では、source = 1, interval = 10000ms に設定されています。

### COMMAND_WRITE_CHARACTERISTIC_UUID (デバイス操作)
ボード上のデバイスの設定や、Notifyの設定などを行います。

フォーマット

| |Command (1Byte) | Payload (17Byte) | 説明 |
----|----|----|----
| Control display | 0 | {0, 0, 0, 0, 0, 0, 0, 0, 0, 0, 0, 0, 0, 0, 0, address_x, address_y} | Write textで使用するindexアドレスを指定します | |
| Write text | 1 | {length of text, (text max 16Byte)} | 任意のテキストを書き込み | Control displayで設定したアドレスは自動的にインクリメントされません|
| Clear display| 2| don't care | ディスプレイをクリア| |
| Write LED | 3 | {0, 0, 0, 0, 0, 0, 0, 0, 0, 0, 0, 0, 0, 0, 0, port, value} |  |
| Buzzer | 4 | {0, 0, 0, 0, 0, 0, 0, 0, 0, 0, 0, 0, 0, 0, 0, 0, value(0:OFF / 1:ON)} |  |
| GPIO Direction | 5 | {0, 0, 0, 0, 0, 0, 0, 0, 0, 0, 0, 0, 0, 0, 0, port, direction(0:Input / 1:Output)} |  |
| GPIO Digital Write  | 6 | {0, 0, 0, 0, 0, 0, 0, 0, 0, 0, 0, 0, 0, 0, 0, port, value} |  |
| GPIO Analog Write  | 7 | {0, 0, 0, 0, 0, 0, 0, 0, 0, 0, 0, 0, 0, 0, 0, port, value} |  |
| I2C Start transmission | 8 | {0, 0, 0, 0, 0, 0, 0, 0, 0, 0, 0, 0, 0, 0, 0, 0, address} |  |
| I2C Write data | 9 | {0, 0, 0, 0, 0, 0, 0, 0, 0, 0, 0, 0, 0, 0, 0, 0, data} |  |
| I2C Stop transmission | 10 | {0, 0, 0, 0, 0, 0, 0, 0, 0, 0, 0, 0, 0, 0, 0, 0, 0} |  |
| I2C Request from | 11 | {0, 0, 0, 0, 0, 0, 0, 0, 0, 0, 0, 0, 0, 0, 0, 0, address} |  |
| I2C Read request | 12 | {0, 0, 0, 0, 0, 0, 0, 0, 0, 0, 0, 0, 0, 0, 0, 0, 0} |  |
| Set digital GPIO port for read | 13 | {0, 0, 0, 0, 0, 0, 0, 0, 0, 0, 0, 0, 0, 0, 0, 0, port} |  |
| Set analog GPIO port for read | 14 | {0, 0, 0, 0, 0, 0, 0, 0, 0, 0, 0, 0, 0, 0, 0, 0, port} |  |
| Set display font size| 15 | {0, 0, 0, 0, 0, 0, 0, 0, 0, 0, 0, 0, 0, 0, 0, 0, fontsize(1~3)} |  |
| Write LED Byte | 16 | {0, 0, 0, 0, 0, 0, 0, 0, 0, 0, 0, 0, 0, 0, 0, 0, value} |  |
| SW Notify config | 17 | {0, 0, 0, 0, 0, 0, 0, 0, 0, 0, 0, 0, 0, source(0:Disable / 1:SW1, 2:SW2, 3:SW1 & SW2), mode(0:LOW / 1:CHANGE / 2:RISING / 3:FALLING), interval[1], interval[0]} |  |
| Temperature Notify config | 18 | {0, 0, 0, 0, 0, 0, 0, 0, 0, 0, 0, 0, 0, 0, source(0:Disable / 1:Temperature), interval[1], interval[0]} |  |
| Read value request | 32 | {0, 0, 0, 0, 0, 0, 0, 0, 0, 0, 0, 0, 0, 0, 0, source(0:SW / 1:Accel / 2:Temp / 3:DIgital GPIO / 4:Analog GPIO / 5:I2C)} |  |

### COMMAND_RESPONSE_CHARACTERISTIC_UUID (デバイスからread)
`COMMAND_WRITE_CHARACTERISTIC_UUID`にて設定されたデバイスの値を取得します。設定されたデバイスソースによって、送信されるデータが異なります。

|Source|Value format|
----|----
|Switch|{0, 0, SW2, SW1}|
|Accel| {0, X, Y, Z} |
|Temperature|温度が100倍された値 |
|GPIO Digital| {0, 0, 0, value} |
|GPIO Analog| {0, 0, 0, value}|
|I2C| {0, 0, (0:invalid / 1:valid), value} |

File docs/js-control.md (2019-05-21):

# JavaScript から LINE Things Board を制御する

LINE Things developemt boardのファームウェアが持っているGATT Characteristicを利用することで、
自由にボードに乗っているハードウェアや GPIO を簡単に制御することができるようになっています。

ここで紹介する方法を用いると、ファームウェアの書き換えなしに、LIFFのJavaScriptによってデバイスの挙動を設定することが可能です。
制御を簡単に行うための、JavaScriptクラスを用意しています。
例えば任意のタイミングでデバイスからNotifyさせたり、各種センサの値を任意に設定したり、取得することが可能です。
LIFFからだけではなく、自動通信など、キャラクタリスティックに読み書きができる環境であれば、同じようにデバイスの操作をすることが可能です。

なお、このキャラクタリスティックからディスプレイ操作をすると、デバイスのOLEDの表示は更新されなくなります。
再度自動的に表示させたい場合はデバイスの電源を入れ直すかリセットボタンを押してください。

`liff-app/linethings-dev-js-control` に格納されているコードではここで紹介している方法でコントロールできる全ての機能を試すことができます。
まずはこちらを試してみると雰囲気をつかめるかもしれません。

その他サンプルコードを、`liff-app/examples-js-control` に格納しているので、こちらを参考にしてみてください。

## 利用するにあたって
この機能を利用する場合はLINE Things development boardのFirmwareバージョンが2以上でなくてはなりません。
LIFFを開いた際、アラートが表示された場合はファームウェアのアップデートをしてください。

詳しくは[ファームウェアの書き込み方法](https://github.com/line/line-things-dev-board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)
を御覧ください。

## LIFF からの利用方法
JavaScriptから利用するためのクラスは`things-dev-board.js` に実装されています。
使用する際にはhtmlからこのファイルを読み込んでください。
LIFF の BLE プラグインに対して、`requestDevice()` した際に帰ってくる返り値をコンストラクタに代入して `connect()` してください。

利用するには、LINE EngineeringにてLIFFのendpointを作成したLIFFに設定する必要があります。
いくつかサンプルを用意しています。初めて利用する際はそれを参考にしたり、拡張すると便利です。
(GitHub pages も利用可能です)

|ファイル名|内容|
----|----
|default|利用できるすべての機能を試してみることができます|
|display|LIFFからデバイスのOLEDを制御するサンプルです|
|led-blink|LIFFからLEDを制御します。Arduinoライクにsetup(), loop()を利用できるようにしています|
|notify|SWとTemperatureの値を定期的にnotifyするサンプルです|

led-blinkはloopコードを含んでいます。あくまでArduinoライクに動かすためにそうしていますが、端末の電力を消費します。
本来はイベントドリブンで書くべきなので、あくまでも動かせるデモとしてのみ参考にしてみてください。

## JavaScriptライブラリ機能詳細

### Service UUIDの書き換え
`writeAdvertUuid(uuid)`
uuidにはテキストとして書き換えたいUUIDを設定します。なお、このメソッドを実行しても即座には反映さ
れず、デバイスのリセットとLIFFの再立ち上げが必要です。

この機能のみ、Version 1から利用可能です。

一度書き換えたUUIDはデバイスのFlashに格納されて、電源を切ったとしても最後に書き込んだService UUIDが使用されます。
デフォルトのService UUIDに戻したい場合、SW1スイッチを押しながらリセットボタンを押してください。

### Versionの読み込み
`deviceVersionRead()`
このメソッドを実行したあと、 `versionRead()` にてファームウェアのバージョンを取得します。
なお、以前のバージョンのファームウェアはバージョン情報のキャラクタリスティックが存在しないため、
存在しないキャラクタリスティックとして検出し、その場合はバージョン1を返します。

これから説明している機能はVersion 2以上で利用可能となります。

### Display 制御
この操作を行うと、ボード上でディスプレイの更新は行われなくなり、完全にこれから紹介する方法で
ディスプレイの表示内容を操作することになります。
もとに戻したい場合は、デバイスの電源を入れ直すかリセットボタンを押します。

#### ディスプレイクリア
`displayClear()`
ディスプレイ表示をクリアします。

#### ディスプレイ書き込みポジション指定
`displayControl(addr_x, addr_y)`
テキストを書き込むアドレスを指定します。それぞれ0~63の値を取ります。

#### キャラクタフォントサイズ指定
`displayFontSize(size)`
フォントサイズを指定します。指定可能な値は1, 2, 3です。

#### キャラクタ書き込み
`displayWrite(text)`
textには書き込みたい文字列(最大16文字)を指定します。16文字を消える場合は複数回に分けて実行します。

### LED制御
#### 単体制御
`ledWrite(port, value)`
portは対象のLEDを指定します。2~5を指定可能です。それぞれデバイスのLED DS2~5が対応しています。valueは0で消灯、1で点灯です。

#### 全体制御
`ledWriteByte(value)`
全てのLEDを一度の制御します。

### ブザー制御
`buzzerControl(value)`
1を書き込むとbuzzerがなります。

### GPIOデジタル制御
#### 入出力設定
`gpioPinMode(port, value)`
portは対象のGIPOポートを指定します。valueは0でINPUT, 1でOUTPUTです。

#### 出力
`gpioDigitalWrite(port, value)`
portは対象のGIPOポートを指定します。valueは対象ポートの出力レベルを0または1で設定します。

### GPIOアナログ出力
`gpioAnalogWrite(port, value)`
portは対象のGIPOポートを指定します。valueは対象ポートの出力レベルを0から255で指定します。

### I2C
`i2cStartTransmission(address)`
`i2cWrite(value)`
`i2cStopTransmission()`
`i2cRequestFrom(address, length)`
`i2cReadRequest(device)`

基本的にはArduinoのI2Cと同じように使用するので、そちらを参考にしてください。 `i2cReadRequest(device)` は
I2Cデバイスからデータを読み込み、Dev Board内のバッファに格納します。実際のそのデータをLIFFに転送するには
 `readReq(cmd)` と `deviceRead()` を組み合わせて行います。

### デバイスからのデータリード
デバイスからのデータリードは2段階で行われます。まず、デバイス内で読み込みたいデータをそれぞれのバッファに格納します。
deviceおよびportで対象となるデバイスのアドレスや、読み込むポート番号を指定します。なお、スイッチ、加速度センサ、
温度に関してはこのステップは不要で、いきなり `readReq(cmd)` を実行します。

`i2cReadRequest(device)`
`gpioDigitalReadReq(port)`
`gpioAnalogReadReq(port)`

読み込みたいデータをバッファに格納したら、実際に読み込みたいソースを指定します。
`readReq(cmd)`

|値|説明|
----|----
|0|Switch|
|1|加速度センサ|
|2|温度|
|3|デジタルGPIOの値|
|4|アナログGPIOの値|
|5|I2Cのデータ|

最後に、`deviceRead()`を実行して、デバイスのバッファに格納されたデータを読み取ります。

### Notification
#### Switch
`swNotifyEnable(source, mode, interval, callback)`
スイッチの状態に変化が起きたときだけNotifyします。`swNotifyDisable()`で停止します。
##### source

|値|説明|
----|----
|0|disable|
|1|SW1|
|2|SW2|
|3|SW1 or SW2|

##### mode

|値|説明|
----|----
|0|LOW|
|1|CHANGE|
|2|RISING|
|3|FALLING|

##### interval
一度割り込みを起こしてから次に割り込みを許可するまでの時間をミリ秒で指定します。これを使用することでチャタリング防止機能をつけることが可能です。

##### callback
Notificationが発生したときに実行されるメソッドを指定します。

#### Temperature
`tempNotifyEnable(interval, callback)`
温度を定期的にNotifyします。`tempNotifyDisable()`で停止します。
なお、 `i2cStartTransmission(address)`を実行したあと、この機能は `i2cStopTransmission()` が実行されるまで無視されます。

##### source

|値|説明|
----|----
|0|disable|
|1|enable|

##### callback
Notificationが発生したときに実行されるメソッドを指定します。

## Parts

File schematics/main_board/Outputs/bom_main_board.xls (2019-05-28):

LibRef | Designator | Quantity | value | Footprint | Description | 部品メーカー | メーカー品番 | 代替可否 | 部品提供 | 実装なし | コメント
PKLCS1212E4001 | BZ1 | 1 |  | PKLCS1212E4001 | PKLCS1212E4001 | Murata | PKLCS1212E4001-R1
Cap1 | C1, C2 | 2 | 1000pF | 2012[0805] |  | Yageo | CC0805KRX7R9BB102 | ok
Cap1 | C3, C4, C5, C9, C12 | 5 | 0.1uF | 2012[0805] |  | Yageo | CC0805ZRY5V9BB104 | ok
Cap1 | C6, C15, C16 | 3 | 4.7uF | 2012[0805] |  | Murata | GRM21BR71A475ME51L | ok
Cap1 | C7, C8 | 2 | 300pF | 2012[0805] |  |  |  |  |  | yes
Cap1 | C10, C11, C17 | 3 | 10uF | 2012[0805] |  | Yageo | CC0805MKY5V6BB106 | ok
Cap2 | C13 | 1 | 100uF | CE04-8 |  |  |  |  |  | yes
Cap2 | C14 | 1 | 470uF | CE04-8 |  |  |  |  |  | yes
B2B-XH-A | CN1, CN2, CN3 | 3 |  | CND-B2B-XH-A | XHシリーズ ベース付ポスト トップ型 2.5mmピッチ 250V 3A |  |  |  |  | yes
LL4148 | D1 | 1 |  | SOD80 |  | ON Semiconductor | LL4148 | ok
SS14 | D2 | 1 |  | DO-214AC |  | Taiwan Semiconductor | SS12 E3
LED | DS1, DS2, DS3, DS4, DS5, DS6, DS7 | 7 |  | 3216[1206]+A |  | Light-On | LTST-C150GKT | ok
USB-B | J1 | 1 |  | USB-B-MICRO | USB 1.1, Right Angle, Thru-Hole, B Type, Receptacle, 4 Position, White | Amphenol FCI | 10104110-0001LF | ok
Inductor | L1 | 1 | 100uH | INDUCTOR-1212 |  |  |  |  |  | yes
NRF52-MODLE | M1 | 1 |  | NRF52-MODLE | NRF52-MODLE |  |  |  | yes |  | 14P Pin Header * ２
SSD1306-096-12864 | M2 | 1 |  | SSD1306-096-12864 | SSD1306-096-12864 |  |  |  | yes |  | 4P Pin Frame * 1
BH-4-4P | M3, M4 | 2 |  | BH-4-4P | BH-4-4P |  |  |  |  | yes
Header 10X2 | P1 | 1 |  | HDR2X10 | Header, 10-Pin, Dual row |  |  |  |  | yes
1125-4P | P2, P6, P7, P8 | 4 |  | 1125-4P | Seed Studio Grobe connector |  |  |  |  | yes
Header 2 | P3 | 1 |  | HDR1X2 | Header, 2-Pin |  |  |  |  | yes
Header 3 | P4 | 1 |  | HDR1X3 | Header, 3-Pin |  |  |  | yes |  | 3P Pin Header * 1
Header 6 | P5 | 1 |  | HDR1X6 | Header, 6-Pin |  |  |  |  | yes
2N7002 | Q1, Q2 | 2 |  | SOT23-3 | N-Channel MOSFET | ON Semiconductor | 2N7002KT1G | ok
Res | R1, R2, R3, R4, R5, R14, R15, R17, R20 | 9 | 1k | 2012[0805] |  | Vishay | CRCW08051K00JNEAC | ok
Res | R6, R7, R8, R9 | 4 | 4.7k | 2012[0805] |  | Vishay | CRCW08054K70JNEAC | ok
Res | R10, R11 | 2 | 0.2 | 6332[2512] |  |  |  |  |  | yes
Res | R12 | 1 | 470 | 2012[0805] |  | Yageo | RC0805JR-07470RL | ok
Res | R18 | 1 | 0 | 2012[0805] |  | Bourns | CR0805-J/-000ELF | ok
Res | R19 | 1 | 100k | 2012[0805] |  | Bourns | CR0805-FX-1003ELF | ok
TL3342F160QG | SW1, SW2 | 2 |  | TL3342F160QG |  | E-Switch | TL3342F160QG | ok
MSK-12C01-07 | SW3 | 1 |  | MSK-12C01-07 |  | ALPS | SSSS811101 | ok
DRV8830DGQR | U1, U2 | 2 |  | MSOP10TPH | DRV8830DGQR |  |  |  |  | yes
MMA8452Q | U3 | 1 |  | QFN16-0.5 | MMA8452AQ | NXP | MMA8452QR1
AT30TS74 | U4 | 1 |  | SOIC8 | AT30TS74 | Microchip | AT30TS74-SS8M-T
CP2102N | U5 | 1 | Value | QFN28-0.5 | CP2102N | Silicon Labs | CP2102N-A01-GQFN28R
DMG3415 | U6 | 1 |  | SOT23-3 | DMG3415 | Diodes Incorporated | DMG3415U-7
AP2112 | U7 | 1 |  | SOT23-5 | AP2112 | Diodes Incorporated | AP2112K-3.3TRG1

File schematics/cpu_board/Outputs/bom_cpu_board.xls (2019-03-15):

LibRef | Designator | Quantity | value | Footprint | Description | 部品メーカー | メーカー品番 | 実装なし | コメント
Cap1 | C1 | 1 | 10uF | 1608[0603] |  | Taiyoyuden | JMK107ABJ106MA-T
Cap1 | C2 | 1 | 1uF | 1608[0603] |  | Taiyoyuden | LMK107B7105MA-T
Cap1 | C3, C4 | 2 | 12p | 1608[0603] |  | Kemet | C0603C120J5GACTU
LL4148 | D1 | 1 |  | SOD80 |  | ON Semiconductor | LL4148
Inductor | L1 | 1 | 10uH | 2012[0805] |  | Taiyoyuden | LBR2012T100K
MDBT42Q | M1 | 1 |  | MDBT42Q | MDBT42Q | Raytac | MDBT42Q-512KV2
Header 14 |  | 2 |  | HDR1X14 |  |  |  |  | 14P Pin Headerを２つつける（Designatorはないが、基板の両端)
Header 4 | P1 | 1 |  | HDR1X4 |  |  |  | yes
Res | R1 | 1 | 10k | 1608[0603] |  | Yageo | RC0603JR-0710KL
TL3342F160QG | SW1 | 1 |  | TL3342F160QG |  | E-Switch | TL3342F160QG
XTAL-MC-146 | Y1 | 1 | 32.768KHz | MC-146 |  | EPSON Timing | MC-146 32.7680KA-A0:ROHS

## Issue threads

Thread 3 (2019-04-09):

回路図、アートワーク図のPDFファイル

matsujirushi, 2019-04-09:
Circuit Studioをインストールしなくても確認できるように、回路図、アートワーク図をPDFファイルでアップロードしていただけないでしょうか。
よろしくお願い致します。

cpulabs, 2019-04-10:
表・裏のアートワーク図を追加しました。回路図のリンクは間違っていたので修正しました。

Closed 2019-04-10.

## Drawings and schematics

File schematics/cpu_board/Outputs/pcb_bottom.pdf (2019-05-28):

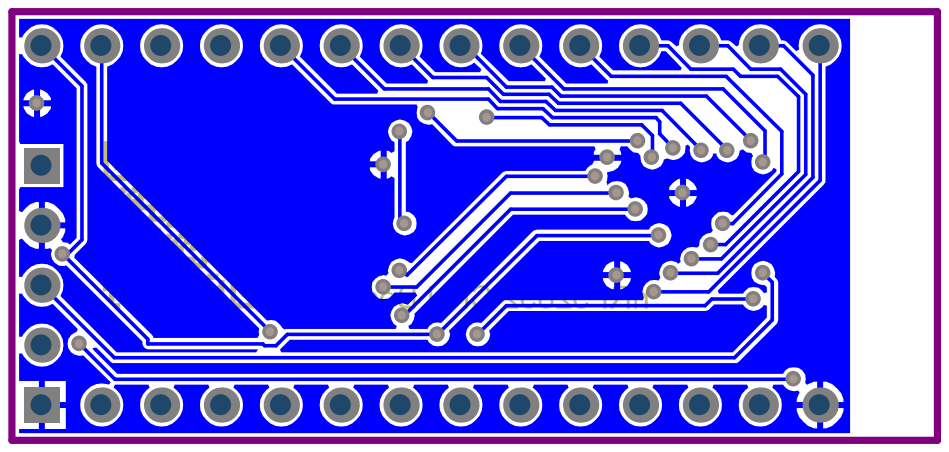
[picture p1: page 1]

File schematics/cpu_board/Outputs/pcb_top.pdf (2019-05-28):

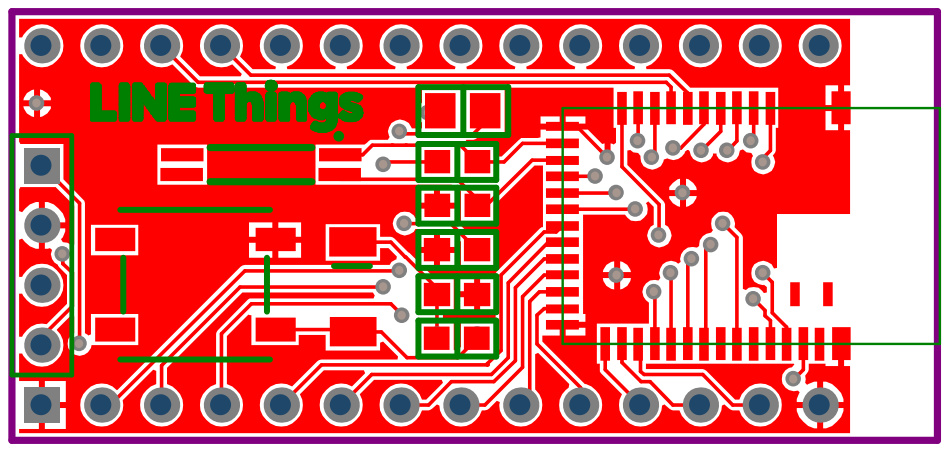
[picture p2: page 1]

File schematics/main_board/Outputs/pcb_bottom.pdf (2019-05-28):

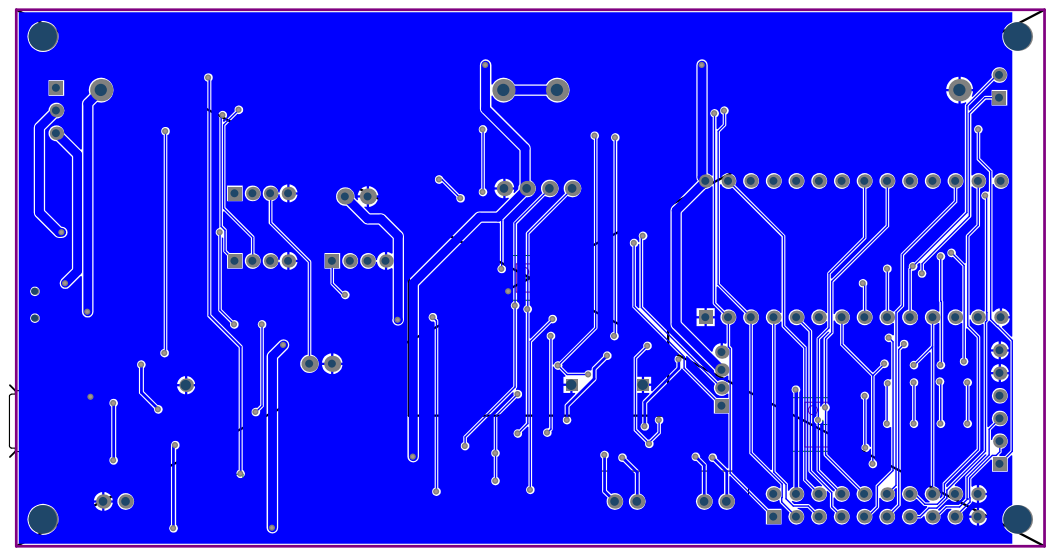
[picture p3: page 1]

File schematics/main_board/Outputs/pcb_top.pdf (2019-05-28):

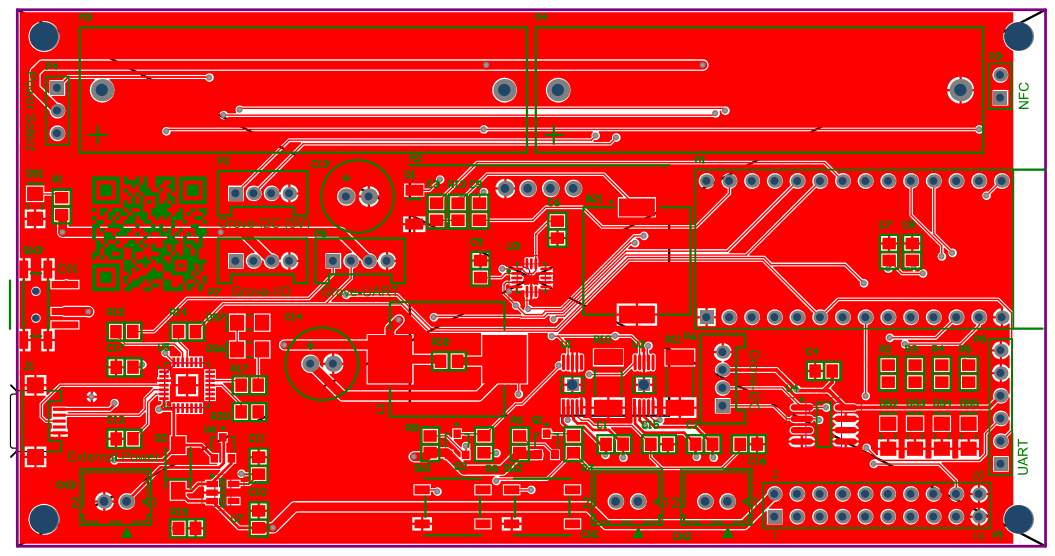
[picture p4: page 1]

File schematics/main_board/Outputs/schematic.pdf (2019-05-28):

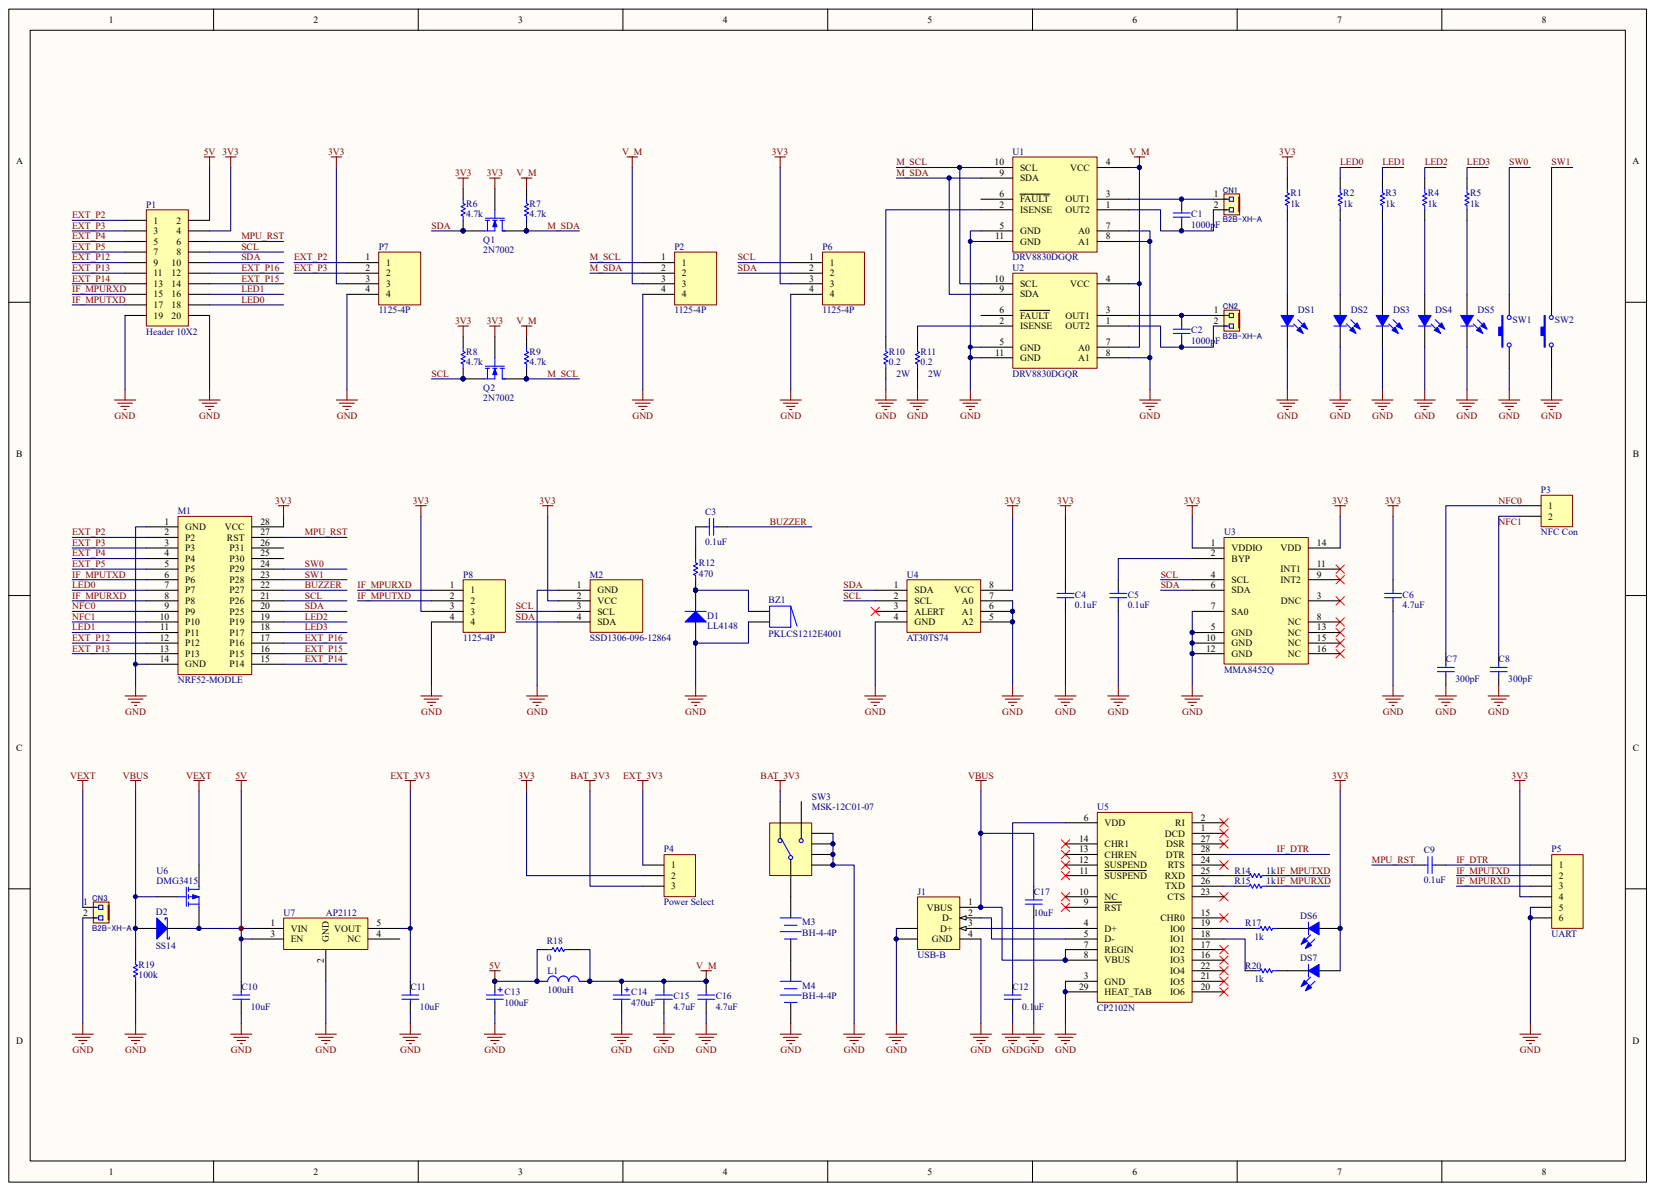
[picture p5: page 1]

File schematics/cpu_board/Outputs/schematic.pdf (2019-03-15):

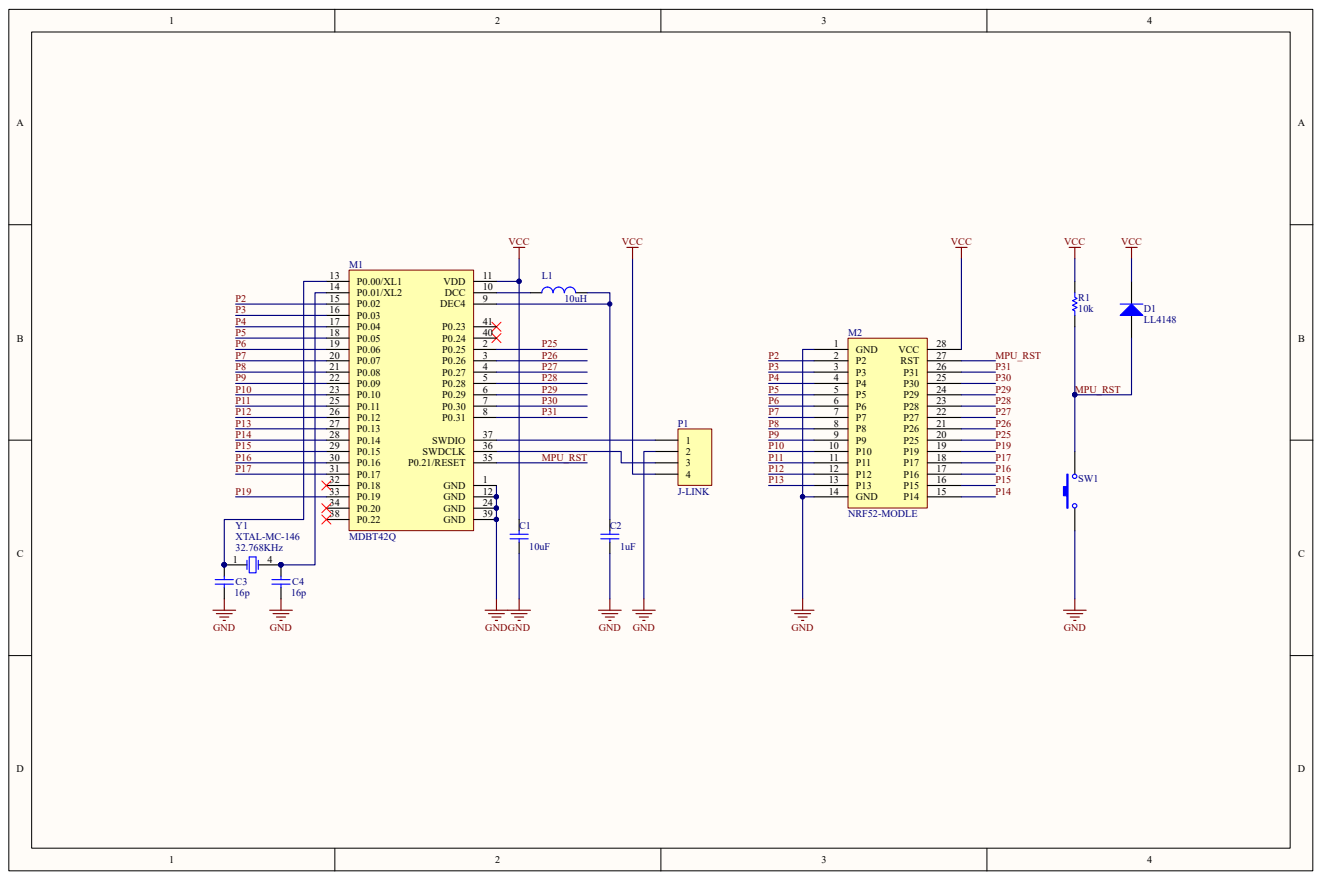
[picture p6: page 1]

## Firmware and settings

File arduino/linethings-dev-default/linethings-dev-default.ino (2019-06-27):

/**
 * Default firmware for LINE Things development board
 * This firmware suppoted 2 type of operation.
 * - Demo mode (NOTIFY_BOARD_STATE_CHARACTERISTIC, WRITE_BOARD_STATE_CHARACTERISTIC)
 *    In this mode, you can get or set whole board state of the LINE Things dev board at once.
 *    Used in combination with LIFF in /liff-app/linethings-dev-default of repository.
 *
 * - Command control mode / Notify switch, temperature state
 *    In this mode, all sensors and individual GPIOs can be controlled from command characteristic.
 *    Easy to hack dev board from LIFF and automatic communication scenario without firmware changes.
 *    Used in combination with Javascript library for LIFF in /liff-app/js-control of repository.
 *    See here for details.
 *    https://line.github.io/line-things-dev-board/liff-app/js-control/
 */

#include <bluefruit.h>
#include <Wire.h>
#include <Adafruit_GFX.h>
#include <Adafruit_SSD1306.h>
#include <SparkFun_MMA8452Q.h>
#include <linethings_temp.h>
#include <Adafruit_LittleFS.h>
#include <InternalFileSystem.h>

using namespace Adafruit_LittleFS_Namespace;

// Debug On / Off
//#define USER_DEBUG
// BLE Default Advertising UUID
#define DEFAULT_ADVERTISE_UUID "f2b742dc-35e3-4e55-9def-0ce4a209c552"
// BLE Service UUID
#define DEVBOARD_SERVICE_UUID "f2b742dc-35e3-4e55-9def-0ce4a209c552"
#define NOTIFY_BOARD_STATE_CHARACTERISTIC_UUID "e90b4b4e-f18a-44f0-8691-b041c7fe57f2"
#define WRITE_BOARD_STATE_CHARACTERISTIC_UUID "4f2596d7-b3d6-4102-85a2-947b80ab4c6f"
#define VERSION_CHARACTERISTIC_UUID "be25a3fe-92cd-41af-aeee-0a9097570815"
#define COMMAND_WRITE_CHARACTERISTIC_UUID "5136e866-d081-47d3-aabc-a2c9518bacd4"
#define COMMAND_RESPONSE_CHARACTERISTIC_UUID "1737f2f4-c3d3-453b-a1a6-9efe69cc944f"
#define NOTIFY_SW_CHARACTERISTIC_UUID "a11bd5c0-e7da-4015-869b-d5c0087d3cc4"
#define NOTIFY_TEMP_CHARACTERISTIC_UUID "fe9b11a8-5f98-40d6-ae82-bea94816277f"
#define PSDI_SERVICE_UUID "e625601e-9e55-4597-a598-76018a0d293d"
#define PSDI_CHARACTERISTIC_UUID "26e2b12b-85f0-4f3f-9fdd-91d114270e6e"
// Device name and version
#define BLE_DEV_NAME "LINE Things dev board"
#define FIRMWARE_VERSION 3
// Device and pin
#define SW1 29
#define SW2 28
#define LED_DS2 7
#define LED_DS3 11
#define LED_DS4 19
#define LED_DS5 17
#define GPIO2 2
#define GPIO3 3
#define GPIO4 4
#define GPIO5 5
#define GPIO12 12
#define GPIO13 13
#define GPIO14 14
#define GPIO15 15
#define GPIO16 16
#define BUZZER_PIN 27
#define ACCEL_ADDR 0x1C

/*********************************************************************************
* Internal config file
*********************************************************************************/
#define UUID_FILENAME "/uuidconfig.txt"
File file(InternalFS);

/*********************************************************************************
* I2C Peripherals
*********************************************************************************/
// I2S Display
Adafruit_SSD1306 display(128, 64, &Wire, -1);
// Acceleration sensor. (MMA8452)
MMA8452Q accel(ACCEL_ADDR);
bool accel_valid;
// Temperature sensor (AT30TS74)
ThingsTemp temp = ThingsTemp();

/*********************************************************************************
* Buzzer
*********************************************************************************/
SoftwareTimer buzzer;

// Callback for buzzer control @1khz
void buzzerEvent(TimerHandle_t xTimerID) {
  digitalWrite(BUZZER_PIN, !digitalRead(BUZZER_PIN));
}

void buzzerStart() {
  pinMode(BUZZER_PIN, OUTPUT);
  buzzer.begin(1, buzzerEvent);
  buzzer.start();
}

void buzzerStop() {
  buzzer.stop();
  digitalWrite(BUZZER_PIN, 0);
}

/*********************************************************************************
* Debug print
*********************************************************************************/
void debugPrint(String text) {
#ifdef USER_DEBUG
  text = "[DBG]" + text;
  Serial.println(text);
#endif
}

/*********************************************************************************
* BLE settings
*********************************************************************************/
// Advertising service UUID
uint8_t blesv_user_uuid[16];
BLEService blesv_user = BLEService(blesv_user_uuid);

// LINE Things PSDI service
uint8_t blesv_line_uuid[16];
uint8_t blesv_line_product_uuid[16];
BLEService blesv_line = BLEService(blesv_line_uuid);
BLECharacteristic blesv_line_product = BLECharacteristic(blesv_line_product_uuid);

// LINE Things development board service
uint8_t blesv_devboard_uuid[16];
uint8_t blech_notify_board_state_uuid[16];
uint8_t blech_write_board_state_uuid[16];
uint8_t blech_version_uuid[16];
uint8_t blech_command_write_uuid[16];
uint8_t blech_command_response_uuid[16];
uint8_t blech_notify_sw_uuid[16];
uint8_t blech_notify_temp_uuid[16];
BLEService blesv_devboard = BLEService(blesv_devboard_uuid);
BLECharacteristic blech_notify_board_state = BLECharacteristic(blech_notify_board_state_uuid);
BLECharacteristic blech_write_board_state = BLECharacteristic(blech_write_board_state_uuid);
BLECharacteristic blech_version = BLECharacteristic(blech_version_uuid);
BLECharacteristic blech_command_write = BLECharacteristic(blech_command_write_uuid);
BLECharacteristic blech_command_response = BLECharacteristic(blech_command_response_uuid);
BLECharacteristic blech_notify_sw = BLECharacteristic(blech_notify_sw_uuid);
BLECharacteristic blech_notify_temp = BLECharacteristic(blech_notify_temp_uuid);

// UUID Converter
void strUUID2Bytes(String strUUID, uint8_t binUUID[]) {
  String hexString = String(strUUID);
  hexString.replace("-", "");

  for (int i = 16; i != 0; i--) {
    binUUID[i - 1] = hex2c(hexString[(16 - i) * 2], hexString[((16 - i) * 2) + 1]);
  }
}

char hex2c(char c1, char c2) { return (nibble2c(c1) << 4) + nibble2c(c2); }

char nibble2c(char c) {
  if ((c >= '0') && (c <= '9')) return c - '0';
  if ((c >= 'A') && (c <= 'F')) return c + 10 - 'A';
  if ((c >= 'a') && (c <= 'f')) return c + 10 - 'a';
  return 0;
}

void bleConfigure(int power) {
  // UUID setup
  strUUID2Bytes(PSDI_SERVICE_UUID, blesv_line_uuid);
  strUUID2Bytes(PSDI_CHARACTERISTIC_UUID, blesv_line_product_uuid);
  strUUID2Bytes(DEVBOARD_SERVICE_UUID, blesv_devboard_uuid);
  strUUID2Bytes(NOTIFY_BOARD_STATE_CHARACTERISTIC_UUID, blech_notify_board_state_uuid);
  strUUID2Bytes(WRITE_BOARD_STATE_CHARACTERISTIC_UUID, blech_write_board_state_uuid);
  strUUID2Bytes(VERSION_CHARACTERISTIC_UUID, blech_version_uuid);
  strUUID2Bytes(COMMAND_RESPONSE_CHARACTERISTIC_UUID, blech_command_response_uuid);
  strUUID2Bytes(COMMAND_WRITE_CHARACTERISTIC_UUID, blech_command_write_uuid);
  strUUID2Bytes(NOTIFY_SW_CHARACTERISTIC_UUID, blech_notify_sw_uuid);
  strUUID2Bytes(NOTIFY_TEMP_CHARACTERISTIC_UUID, blech_notify_temp_uuid);
  // BLE start
  Bluefruit.begin();
  // Set max Tx power
  // Accepted values are: -40, -30, -20, -16, -12, -8, -4, 0, 4
  Bluefruit.setTxPower(power);
  // BLE devicename
  Bluefruit.setName(BLE_DEV_NAME);
  Bluefruit.Periph.setConnInterval(12, 1600); // connection interval min=20ms, max=2s
  // Set the connect/disconnect callback handlers
  Bluefruit.Periph.setConnectCallback(bleConnectEvent);
  Bluefruit.Periph.setDisconnectCallback(bleDisconnectEvent);
}

void bleStartAdvertising(void) {
  Bluefruit.Advertising.addFlags(BLE_GAP_ADV_FLAGS_LE_ONLY_GENERAL_DISC_MODE);
  Bluefruit.Advertising.addTxPower();
  Bluefruit.Advertising.setFastTimeout(0);
  Bluefruit.Advertising.setInterval(32, 32); // interval : 20ms
  Bluefruit.Advertising.restartOnDisconnect(true);
  // Add service uuid for find from LINE app
  Bluefruit.Advertising.addUuid(BLEUuid(blesv_user_uuid));
  Bluefruit.ScanResponse.addName();
  Bluefruit.Advertising.start();
}

void bleSetupServicePsdi(void) {
  blesv_line.begin();
  blesv_line_product.setProperties(CHR_PROPS_READ);
  blesv_line_product.setPermission(SECMODE_ENC_NO_MITM, SECMODE_ENC_NO_MITM);
  blesv_line_product.setFixedLen(sizeof(uint32_t) * 2);
  blesv_line_product.begin();
  uint32_t deviceAddr[] = {NRF_FICR->DEVICEADDR[0], NRF_FICR->DEVICEADDR[1]};
  blesv_line_product.write(deviceAddr, sizeof(deviceAddr));
}

void bleSetupServiceDevice() {
  blesv_devboard.begin();
  blech_notify_board_state.setProperties(CHR_PROPS_NOTIFY);
  blech_notify_board_state.setPermission(SECMODE_ENC_NO_MITM, SECMODE_NO_ACCESS);
  blech_notify_board_state.setFixedLen(16);
  blech_notify_board_state.begin();

  blech_write_board_state.setProperties(CHR_PROPS_WRITE);
  blech_write_board_state.setPermission(SECMODE_ENC_NO_MITM, SECMODE_ENC_NO_MITM);
  blech_write_board_state.setWriteCallback(bleWriteEvent);
  blech_write_board_state.setFixedLen(20);
  blech_write_board_state.begin();

  blech_version.setProperties(CHR_PROPS_READ);
  blech_version.setPermission(SECMODE_ENC_NO_MITM, SECMODE_NO_ACCESS);
  blech_version.setFixedLen(1);
  blech_version.begin();
  blech_version.write8(FIRMWARE_VERSION);

  blech_command_write.setProperties(CHR_PROPS_WRITE);
  blech_command_write.setPermission(SECMODE_ENC_NO_MITM, SECMODE_ENC_NO_MITM);
  blech_command_write.setWriteCallback(bleIoWriteEvent);
  blech_command_write.setFixedLen(20);
  blech_command_write.begin();

  blech_command_response.setProperties(CHR_PROPS_READ | CHR_PROPS_NOTIFY);
  blech_command_response.setPermission(SECMODE_ENC_NO_MITM, SECMODE_NO_ACCESS);
  blech_command_response.setFixedLen(4);
  blech_command_response.begin();

  blech_notify_sw.setProperties(CHR_PROPS_NOTIFY);
  blech_notify_sw.setPermission(SECMODE_ENC_NO_MITM, SECMODE_NO_ACCESS);
  blech_notify_sw.setFixedLen(2);
  blech_notify_sw.begin();

  blech_notify_temp.setProperties(CHR_PROPS_NOTIFY);
  blech_notify_temp.setPermission(SECMODE_ENC_NO_MITM, SECMODE_NO_ACCESS);
  blech_notify_temp.setFixedLen(2);
  blech_notify_temp.begin();
}

void bleSetupServiceUser() {
  blesv_user.begin();
}

// Event for connect BLE central
void bleConnectEvent(uint16_t conn_handle) {
  char central_name[32] = {0};

  BLEConnection* connection = Bluefruit.Connection(conn_handle);
  connection->getPeerName(central_name, sizeof(central_name));

  String msg = "Connected from " + String(central_name);
  debugPrint(msg);
}

// Event for disconnect BLE central
void bleDisconnectEvent(uint16_t conn_handle, uint8_t reason) {
  (void)reason;
  (void)conn_handle;
  debugPrint("BLE central disconnect");
}

volatile int g_flag_user_write = 0;
volatile int g_data_user_write_led0 = 0;
volatile int g_data_user_write_led1 = 0;
volatile int g_data_user_write_led2 = 0;
volatile int g_data_user_write_led3 = 0;
volatile int g_data_user_write_buzzer = 0;
volatile int g_data_user_write_io2 = 0;
volatile int g_data_user_write_io3 = 0;
volatile int g_data_user_write_io4 = 0;
volatile int g_data_user_write_io5 = 0;
volatile int g_data_user_write_io12 = 0;
volatile int g_data_user_write_io13 = 0;
volatile int g_data_user_write_io14 = 0;
volatile int g_data_user_write_io15 = 0;
volatile int g_data_user_write_io16 = 0;

volatile int g_flag_update_advertiseuuid = 0;
volatile int g_flag_error_advertiseuuid = 0;

/**
 * Format
 *
 * <CMD(1Byte), don't care(2Byte), hash of payload/don't care(1Byte),
 * Payload(16Byte)> CMD0 : Write to peripheral device. LED, buzzer and GPIO
 *    CMD0(0:1Byte), don't care(0:17Byte), Peripheral(x:2Byte)
 * CMD1 : Write new service UUID : When update UUID, Should be self restart MPU:
 *    CMD1(1:1Byte), don't care(0,2Byte), hash of payload(x:1Byte),
 *    UUID(x:16Byte) UUID shoud be send binary.
 */
void bleWriteEvent(uint16_t conn_handle, BLECharacteristic* chr, uint8_t* data, uint16_t len) {
  byte cmd = data[0];
  byte index = data[1];
  byte length = data[2];
  byte hash = data[3];

  Serial.println("UUID Change ");

  if (cmd == 0) {
    // Write peripheral device and GPIO
    g_data_user_write_led0 = (data[19] >> 7) & 1;
    g_data_user_write_led1 = (data[19] >> 6) & 1;
    g_data_user_write_led2 = (data[19] >> 5) & 1;
    g_data_user_write_led3 = (data[19] >> 4) & 1;
    g_data_user_write_buzzer = (data[19] >> 3) & 1;
    g_data_user_write_io2 = (data[19] >> 2) & 1;
    g_data_user_write_io3 = (data[19] >> 1) & 1;
    g_data_user_write_io4 = data[19] & 1;
    g_data_user_write_io5 = (data[18] >> 7) & 1;
    g_data_user_write_io12 = (data[18] >> 6) & 1;
    g_data_user_write_io13 = (data[18] >> 5) & 1;
    g_data_user_write_io14 = (data[18] >> 4) & 1;
    g_data_user_write_io15 = (data[18] >> 3) & 1;
    g_data_user_write_io16 = (data[18] >> 2) & 1;
    g_flag_user_write = 1;
  } else if (cmd == 1) {
    // Write New Advertising UUID
    byte generatedHash = 0;
    for (int i = 0; i < 16; i++) {
      blesv_user_uuid[15 - i] = data[4 + i];
      generatedHash += data[4 + i];
    }

    g_flag_update_advertiseuuid = 1;

    if (generatedHash != hash) {
      g_flag_error_advertiseuuid = 1;
    }
  }
}

typedef struct ble_io_action {
  byte changed = 0;
  int port = 0;
  int value = 0;
} bleIoAction;

typedef struct ble_display_action {
  byte changed = 0;
  int addr_x = 0;
  int addr_y = 0;
} bleDispAction;

typedef struct ble_display_text_action {
  byte changed = 0;
  char text[16];
  byte length = 0;
} bleDispTextAction;

typedef struct ble_i2c_action {
  byte changed = 0;
  byte data = 0;
  byte length = 0;
} bleI2cAction;

typedef struct ble_read_action {
  byte changed = 0;
  byte cmd = 0;
} bleReadAction;

typedef struct ble_notify_action {
  byte changed;
  byte source;
  byte level;
  byte mode;
  unsigned int interval;
} bleNotifyAction;

volatile bleIoAction g_led;
volatile bleIoAction g_led_byte;
volatile bleIoAction g_buzzer;

volatile bleIoAction g_gpio_dir;
volatile bleIoAction g_gpio_w_value;
volatile bleIoAction g_gpio_aw_value;

volatile bleDispAction g_display;
volatile int g_display_clear = 0;
volatile bleDispTextAction g_display_text;
volatile int g_display_fontsize = 0;

volatile bleI2cAction g_i2c_start_transmission;
volatile bleI2cAction g_i2c_w_value;
volatile int g_i2c_stop_transmission;
volatile bleI2cAction g_i2c_request_from;
volatile int g_i2c_read_req;

volatile int g_gpio_r_port;
volatile int g_gpio_ar_port;

volatile bleReadAction g_read_action;

volatile bleNotifyAction g_notify_sw = {
  .changed = 1, .source = 3, .level = 0, .mode = 1, .interval = 50
};
volatile bleNotifyAction g_notify_temp = {
  .changed = 1, .source = 1, .level = 0, .mode = 0, .interval = 10000
};

volatile int g_display_user_mode = 0;
volatile int g_i2c_user_mode = 0;
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
void loop() {
  // Change service UUID
  if (g_flag_update_advertiseuuid) {
    update_advertiseuuid();
  }

  // Set LED and buzzer value
  if (g_flag_user_write) {
    board_user_write();
    g_flag_user_write = 0;
  }

  bool refresh_display = g_flag_display && !g_display_user_mode && !g_i2c_user_mode;
  bool notify_sensor = g_flag_notify && blech_notify_board_state.notifyEnabled();

  float temperature;
  // Read sensor value
  if (!g_i2c_user_mode && (refresh_display || notify_sensor)) {
    temperature = temp.read();
    if (accel_valid) {
      accel.read();
    }
  }

  // Display write (Default)
  if (refresh_display) {
    display.clearDisplay();
    display.setTextSize(1);
    display.setTextColor(WHITE);
    display.setCursor(0, 10);
    if (Bluefruit.connected()) {
      display.println("LINE Things [BLE]");
    } else {
      display.println("LINE Things");
    }
    if (accel_valid) {
      display.print("X:");
      display.println(accel.cx);
      display.print("Y:");
      display.println(accel.cy);
      display.print("Z:");
      display.println(accel.cz);
    } else {
      display.println("X:-");
      display.println("Y:-");
      display.println("Z:-");
    }
    display.print("Temperature:");
    display.println(temperature);
    if (g_data_sw1) {
      display.print("SW1:ON / ");
    } else {
      display.print("SW1:OFF / ");
    }
    if (g_data_sw2) {
      display.println("SW2:ON");
    } else {
      display.println("SW2:OFF");
    }
    display.display();
    g_flag_display = 0;
  }

  if (Bluefruit.connected()) {
    // Notify board state
    if (notify_sensor) {
      if (accel_valid) {
        notify_board_state(accel.cx, accel.cy, accel.cz, temperature, g_data_sw1, g_data_sw2);
      } else {
        notify_board_state(0, 0, 0, temperature, g_data_sw1, g_data_sw2);
      }
      g_flag_notify = 0;
    }
    notify_sw_handler();
    notify_temp_handler();
    command_characteristic_handler();
  }
}

void update_advertiseuuid() {
  if (g_flag_error_advertiseuuid) {
    String errorMsg =
        "[ERROR] : Write new advertising UUID, Hash isn't match. "
        "Please retry it.";
    debugPrint(errorMsg);
    display.clearDisplay();
    display.setTextSize(1);
    display.setTextColor(WHITE);
    display.setCursor(0, 10);
    display.println(errorMsg);
    display.display();
    delay(5000);
    g_flag_update_advertiseuuid = 0;
    g_flag_error_advertiseuuid = 0;
    return;
  }
  configFileWrite(blesv_user_uuid);
  configFileRead();
  debugPrint("BLE advertising uuid changed from LIFF.");
  debugPrint("Enable new uuid after restart MPU.");
  debugPrint("Please push reset button.");
  display.clearDisplay();
  display.setTextSize(1);
  display.setTextColor(WHITE);
  display.setCursor(0, 10);
  display.println("BLE advertising uuid changed from LIFF.");
  display.println("Enable new uuid after restart MPU.");
  display.println("Please push reset button.");
  display.display();
  for (;;);
}

void board_user_write() {
  // Set GPIO output mode
  pinMode(GPIO2, OUTPUT);
  pinMode(GPIO3, OUTPUT);
  pinMode(GPIO4, OUTPUT);
  pinMode(GPIO5, OUTPUT);
  pinMode(GPIO12, OUTPUT);
  pinMode(GPIO13, OUTPUT);
  pinMode(GPIO14, OUTPUT);
  pinMode(GPIO15, OUTPUT);
  pinMode(GPIO16, OUTPUT);
  // Buzzer
  if (g_data_user_write_buzzer) {
    buzzerStart();
  } else {
    buzzerStop();
  }
  // LED
  digitalWrite(LED_DS2, g_data_user_write_led0);
  digitalWrite(LED_DS3, g_data_user_write_led1);
  digitalWrite(LED_DS4, g_data_user_write_led2);
  digitalWrite(LED_DS5, g_data_user_write_led3);
  // GPIO
  digitalWrite(GPIO2, g_data_user_write_io2);
  digitalWrite(GPIO3, g_data_user_write_io3);
  digitalWrite(GPIO4, g_data_user_write_io4);
  digitalWrite(GPIO5, g_data_user_write_io5);
  digitalWrite(GPIO12, g_data_user_write_io12);
  digitalWrite(GPIO13, g_data_user_write_io13);
  digitalWrite(GPIO14, g_data_user_write_io14);
  digitalWrite(GPIO15, g_data_user_write_io15);
  digitalWrite(GPIO16, g_data_user_write_io16);
}

void notify_sw_handler() {
  if (blech_notify_sw.notifyEnabled()) {
    if (g_flag_sw1 && (millis() - g_last_notified_sw1) > g_notify_sw.interval) {
      byte notify[2] = {1, g_data_sw1};  // {SW, value}
      g_flag_sw1 = 0;
      g_last_notified_sw1 = millis();
      debugPrint("SW1 Event");
      blech_notify_sw.notify(notify, sizeof(notify));
    }
    if (g_flag_sw2 && (millis() - g_last_notified_sw2) > g_notify_sw.interval) {
      byte notify[2] = {2, g_data_sw2};  // {SW, value}
      g_flag_sw2 = 0;
      g_last_notified_sw2 = millis();
      debugPrint("SW2 Event");
      blech_notify_sw.notify(notify, sizeof(notify));
    }
  }
}

void notify_temp_handler() {
  if (g_i2c_user_mode) {
    debugPrint("User using I2C from JS. Do not work temperature notify when user using I2C from JS");
    return;
  }
  if (g_flag_io_temp_read && blech_notify_temp.notifyEnabled()) {
    unsigned int temp = tempRead() * 100;
    byte notify[2] = {temp >> 8, temp & 0xff};
    debugPrint("TEMP Event");
    blech_notify_temp.notify(notify, sizeof(notify));
    g_flag_io_temp_read = 0;
  }
}

void notify_board_state(float acc_x, float acc_y, float acc_z, float temperature, int sw1, int sw2) {
  int16_t tx_frame[8] = {
    (int16_t) temperature * 100,
    acc_x * 1000,
    acc_y * 1000,
    acc_z * 1000,
    sw1,
    sw2,
    FIRMWARE_VERSION,
    0
  };
  blech_notify_board_state.notify((uint8_t*)tx_frame, sizeof(tx_frame));
}

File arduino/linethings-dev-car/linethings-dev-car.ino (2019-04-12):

#include <bluefruit.h>
#include <Wire.h>
#include <linethings_motor.h>

/**
 * 2WD BLE R/C Car for LINE Things development board with TI DRV8830 motor driver
 */

// Device Name: Maximum 30 bytes
#define DEVICE_NAME "4WD R/C Car DRV8830 - nRF52"

// User service UUID: Change this to your generated service UUID
// #define USER_SERVICE_UUID "8342d390-3478-483c-8bea-6db308de7d04"

// Accelerometer Service UUID
#define RCCAR_SERVICE_UUID "8922e970-329d-44cb-badb-10070ef94b1d"
// [0] Speed: int8, [1] Direction: int8 (right +, left -), [2] Brake: int8 (true, false)
#define RCCAR_CHARACTERISTIC_UUID "b2a70845-b1d1-4420-b260-fa9551bfe361"

// PSDI Service UUID: Fixed value for Developer Trial
#define PSDI_SERVICE_UUID "E625601E-9E55-4597-A598-76018A0D293D"
#define PSDI_CHARACTERISTIC_UUID "26E2B12B-85F0-4F3F-9FDD-91D114270E6E"

uint8_t userServiceUUID[16];
uint8_t rccarServiceUUID[16];
uint8_t rccarCharacteristicUUID[16];
uint8_t psdiServiceUUID[16];
uint8_t psdiCharacteristicUUID[16];

BLEService userService;
BLEService rccarService;
BLECharacteristic rccarCharacteristic;
BLEService psdiService;
BLECharacteristic psdiCharacteristic;

ThingsMotor motorR(MOTOR_ADDR_CN1); // R
ThingsMotor motorL(MOTOR_ADDR_CN2); // L

void setup() {
  Serial.begin(115200);
  Wire.begin();

  Bluefruit.begin();
  Bluefruit.setName(DEVICE_NAME);

  motorR.control(MOTOR_IDLE, 0);
  motorL.control(MOTOR_IDLE, 0);

  setupServices();
  startAdvertising();
  Serial.println("Ready to Connect");
}

void loop() {
  // printMotorFaultStatus();
  delay(500);
}

void motorWriteCallback(uint16_t conn_handle, BLECharacteristic* chr, uint8_t* data, uint16_t len) {
  if (len < 3) {
    return;
  }

  int8_t speed = map((int8_t)data[0], INT8_MIN, INT8_MAX, -100, 100);
  int8_t direction = data[1];
  int8_t brake = data[2];

  int8_t speedL, speedR;

  if (direction > 0) {
    // Right turn
    speedL = speed;
    speedR = speed * ((double) (INT8_MAX - direction) / (double) INT8_MAX);
  } else {
    // Left turn
    speedL = speed * ((double) (INT8_MIN - direction) / (double) INT8_MIN);
    speedR = speed;
  }

  Serial.print("S: ");
  Serial.print(speed);
  Serial.print(" (");
  Serial.print(speedL);
  Serial.print(":");
  Serial.print(speedR);
  Serial.print(") ");
  Serial.print(" D: ");
  Serial.print(direction);
  Serial.print(" B: ");
  Serial.println(brake);

  if (brake) {
    motorR.control(MOTOR_BRAKE, 0);
    motorL.control(MOTOR_BRAKE, 0);
  } else if (speed > 0) {
    motorR.control(MOTOR_FORWARD, speedR);
    motorL.control(MOTOR_FORWARD, speedL);
  } else if (speed < 0) {
    motorR.control(MOTOR_REVERSE, -speedR);
    motorL.control(MOTOR_REVERSE, -speedL);
  } else {
    motorR.control(MOTOR_IDLE, 0);
    motorL.control(MOTOR_IDLE, 0);
  }
}

void setupServices(void) {
  // Convert String UUID to raw UUID bytes
  strUUID2Bytes(USER_SERVICE_UUID, userServiceUUID);
  strUUID2Bytes(RCCAR_SERVICE_UUID, rccarServiceUUID);
  strUUID2Bytes(RCCAR_CHARACTERISTIC_UUID, rccarCharacteristicUUID);
  strUUID2Bytes(PSDI_SERVICE_UUID, psdiServiceUUID);
  strUUID2Bytes(PSDI_CHARACTERISTIC_UUID, psdiCharacteristicUUID);

  // Setup User Service
  userService = BLEService(userServiceUUID);
  userService.begin();

  rccarService = BLEService(rccarServiceUUID);
  rccarService.begin();

  rccarCharacteristic = BLECharacteristic(rccarCharacteristicUUID);
  rccarCharacteristic.setProperties(CHR_PROPS_WRITE);
  rccarCharacteristic.setWriteCallback(motorWriteCallback);
  rccarCharacteristic.setPermission(SECMODE_ENC_NO_MITM, SECMODE_ENC_NO_MITM);
  rccarCharacteristic.setFixedLen(3);
  rccarCharacteristic.begin();

  // Setup PSDI Service
  psdiService = BLEService(psdiServiceUUID);
  psdiService.begin();

  psdiCharacteristic = BLECharacteristic(psdiCharacteristicUUID);
  psdiCharacteristic.setProperties(CHR_PROPS_READ);
  psdiCharacteristic.setPermission(SECMODE_ENC_NO_MITM, SECMODE_NO_ACCESS);
  psdiCharacteristic.setFixedLen(sizeof(uint32_t) * 2);
  psdiCharacteristic.begin();

  // Set PSDI (Product Specific Device ID) value
  uint32_t deviceAddr[] = { NRF_FICR->DEVICEADDR[0], NRF_FICR->DEVICEADDR[1] };
  psdiCharacteristic.write(deviceAddr, sizeof(deviceAddr));
}

void startAdvertising(void) {
  // Start Advertising
  Bluefruit.Advertising.addFlags(BLE_GAP_ADV_FLAGS_LE_ONLY_GENERAL_DISC_MODE);
  Bluefruit.Advertising.addTxPower();
  Bluefruit.Advertising.addService(userService);
  Bluefruit.ScanResponse.addName();
  Bluefruit.Advertising.restartOnDisconnect(true);
  Bluefruit.Advertising.start(0);
}

// UUID Converter
void strUUID2Bytes(String strUUID, uint8_t binUUID[]) {
  String hexString = String(strUUID);
  hexString.replace("-", "");

  for (int i = 16; i != 0 ; i--) {
    binUUID[i - 1] = hex2c(hexString[(16 - i) * 2], hexString[((16 - i) * 2) + 1]);
  }
}

char hex2c(char c1, char c2) {
  return (nibble2c(c1) << 4) + nibble2c(c2);
}

char nibble2c(char c) {
  if ((c >= '0') && (c <= '9'))
    return c - '0';
  if ((c >= 'A') && (c <= 'F'))
    return c + 10 - 'A';
  if ((c >= 'a') && (c <= 'f'))
    return c + 10 - 'a';
  return 0;
}

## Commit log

2019-03-26 Update README, added image of power select (#1)
    * add power select image file
    * add image file
    * update README
    * update README
2019-04-10 add pdf artwork files. fix link of schematic (#4)
2019-05-21 Support device control from LIFF (#6)
    * add pdf artwork files. fix link of schematic
    * supported adafruit nrf52 ver 0.10.1
    * support JS control
    * added version of notify data
    * changed UUID
    * add js control mode
    * support js-mode notify
    * add README.md for JS mode
    * disable mode change style
    * update firmware
    * update readme
    * update firmware and js-control
    * support version check
    * update readme
    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
    [liff.js, linethings-dev-default.ino]
2019-05-23 fix script about write new uuid (#10)
    * fix script about write new uuid
    * remove extra line
    * typo
    [liff.js]
2019-05-28 delete LINE Things logo in PCB file. fixed schematic and pcb design. (#11)
    * delete LINE Things logo. fixed schematic and pcb design.
    * delete preview file
    [board.GBL, board.GBO, board.GBP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]
2019-06-10 fixed SPI pinassign in the pinassign-image. (#12)
2019-06-27 support adafruit nrf52 lib Ver. 0.11.0 and no accelerometer board (#14)
    * support no accelerometer board
    * fixed coding style. and support adafruit nrf52 lib Ver. 0.11.0
    * update documents
    * update readme. fixed coding style
    [linethings-dev-default.ino]
2026-10-28 docs: document LINE Things development board discontinuation (#16)
